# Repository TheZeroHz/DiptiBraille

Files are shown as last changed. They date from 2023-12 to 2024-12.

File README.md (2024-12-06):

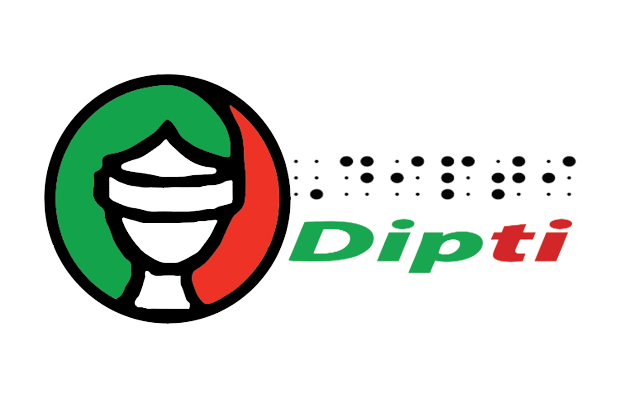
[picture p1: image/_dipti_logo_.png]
>  
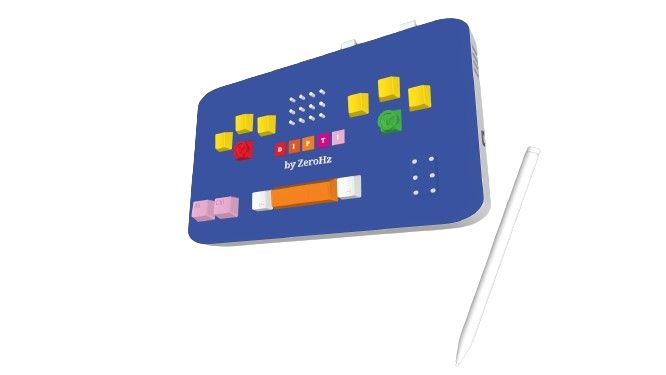
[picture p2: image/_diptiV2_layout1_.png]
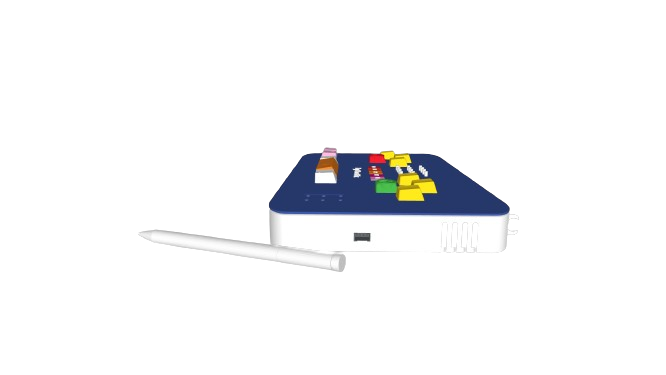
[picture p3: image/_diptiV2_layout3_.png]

<p>DiptiBraille is an affordable literacy device for the visually impaired, enabling text input using Braille. It supports document writing, reading, and audio playback for audiobooks. Users can connect an external Braille display for enhanced feedback. Wireless options include WiFi and WebShare for easy data transfer. Essential communication features like calls and SMS are included for seamless interaction.</p>

># Operating System
[DiptiOS 3](https://drive.google.com/drive/folders/1-XRWvRZWpASW5opDc2k0D57xcp3DkUi7?usp=sharing) is a pioneering operating system meticulously crafted to cater to the unique needs of braille users. Rooted in the robust framework of [FreeRTOS](https://www.freertos.org/RTOS.html), DiptiOS/3 sets a new standard for accessibility, seamlessly integrating with braille display hardware to deliver unparalleled functionality and ease of use.

Experience the sophistication of DiptiBraille's sleek design and intuitive interface, which offer both demo and pro versions. <b><i>Unlock the full potential with the Pro Version, priced at $50</i></b>, or explore its capabilities at no cost with the Demo Version.

|✅ available|❌ not available|🔄 upcoming|🟡 partially available|
|---|---|---|---|

| Features | Pro| Demo | Features | Pro|Demo |  Features | Pro|Demo |
|---|-----|---|---|-----|---|---|---|---|
| 📄 Doc Writing | ✅ |✅ |🖋️ Practice Writing | ✅|❌| 📚 Learn Writing| ✅ |🟡|
|📜 Doc Reading | ✅|✅ | 📖 Practice Reading|  ✅ |❌|📘 Learn Reading| ✅ |🟡|
|🎧 Audio Book |✅|✅ |🎵  Music Library  | 🔄 |❌ | 📞 Call|✅|🟡|
|💬 SMS |✅|❌| 🧮 Calculator | ✅|🟡 |⌨️ BLE KeyBoard| ✅ |✅|
|Bluetooth IconBluetooth|✅| ❌ | WebShare Icon WebShare| ✅ |❌| RemoteShell Icon RemoteShell|🔄| ❌ |
|WiFi Icon WiFi Manager| ✅|🟡 |⬇️ Download Manager |  ✅|❌ |📱 Phone Manager| ✅ |❌|
|⚡Continuous Updates |  ✅ |🟡| 🎮 Games | ✅ |🟡 |📻 Radio| ✅ |✅ |
### DiptiOS/3 Ensures
| OS Feature | Description |
|---|---|
| Optimized Braille Support | Comprehensive support for braille display devices ensures smooth input and output. |
| Intuitive Interface | User-friendly interface tailored for braille users prioritizes ease of navigation. |
| Real-Time Responsiveness | Built on FreeRTOS for instant feedback and interaction. |
| Customization Options | Personalize braille experience with customizable settings. |
| Seamless Connectivity | Effortless data exchange with other devices and platforms. |
| Enhanced Accessibility | Enjoy voice feedback and enhanced audio. |
| Reliability and Stability  | Backed by FreeRTOS for consistent performance and uptime. |

># Open Source Hardware
### Printed Circuit Boards
|**Base Material:** FR-4|**Layers:** 2|**Thickness:** 1.6 mm|**Surface:** HASL(with lead)|**Quality:** IPC 2|**Silkscreen:** White|
|---|---|---|---|---|---|

| Main Unit PCB Outlook | Additional Info | **Display Unit PCB Outlook**  | **Additional Info** |
|---|---|---|---|
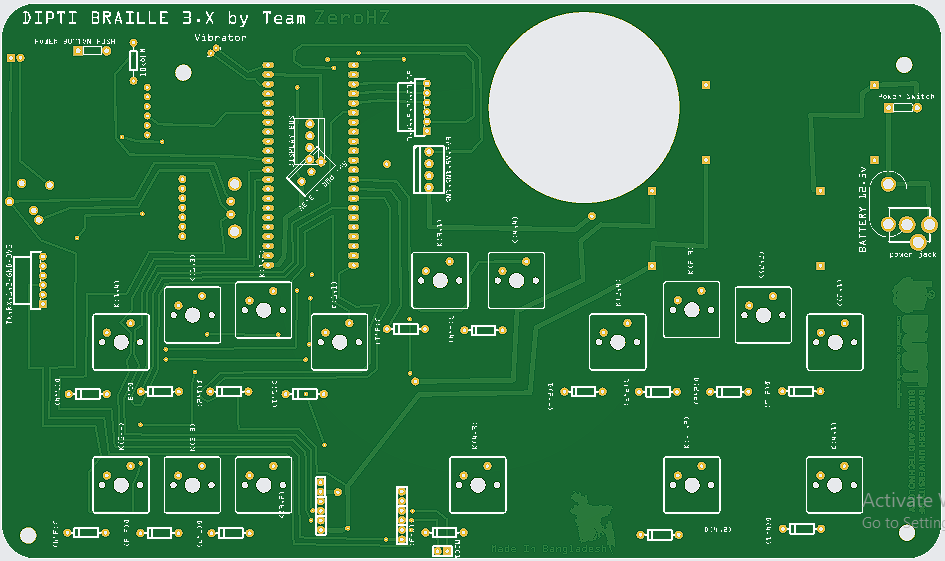
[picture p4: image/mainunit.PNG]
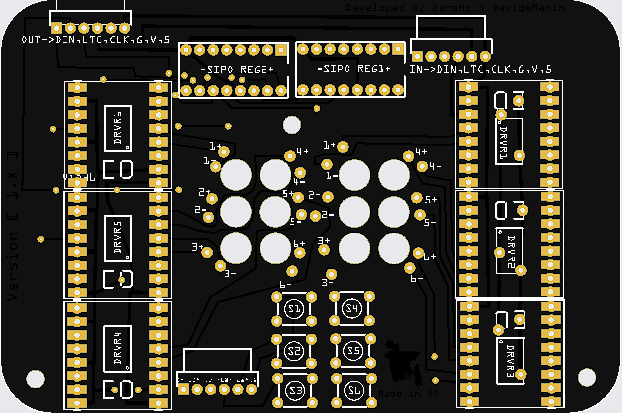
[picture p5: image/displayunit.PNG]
|  |<br> **Dim:** 251x148<br> **Color:** Green<br> |  |<br>**Dim:** 116x77<br> **Color:** Black |

### 🔧 Components List
| Component | Quantity | Component | Quantity |
|---|---|---|---|
| 💻 ESP32 S3 N16R8 | x1 | 📶 SIM800L GSM module | x1 |
| ⌨️ Cherry MX Mechanical keys | x16 | ⌨️ Mechanical Key Cap | x16 |
| 🔊 I2S Amplifier | x1 | 🔊 Speaker 3W | x1 |
| 📇 SD Card Module | x1 | 📇 SD Card | x1 |
| ⚙️ Motor Driver - TB6612FNG | x6 | 🔄 Shift Register - 74HC595 | x2 |
| 🔋 4.2v 2000mAh Li-on Battery | x3 | ⚡ BMS (Circuit Protector) | x1 |
| ⚡ 5V Constant Step Down BUCK Converter | x2 | 🔌 12v Laptop Charger | x1 |
| ⚡ Capacitor | x2 | ⚡ Diode | x20 |
| 🔘 Push Button | x10 | | |

# External Libraries We have Used
- [gpio_viewer](https://github.com/thelastoutpostworkshop/gpio_viewer) by [charlesgiguere](https://github.com/charlesgiguere)
- [ESP32-audioI2S](https://github.com/schreibfaul1/ESP32-audioI2S) by [schreibfaul1](https://github.com/schreibfaul1)
- [ESPFMfGK](https://github.com/holgerlembke/ESPFMfGK) by [Holger Lembke](https://github.com/holgerlembke)
- [WebSerialLite](https://github.com/asjdf/WebSerialLite) by [杨成锴](https://github.com/asjdf)
- [WifiManager](https://github.com/tzapu/WiFiManager) by [tzapu](https://github.com/tzapu)
- [Keypad](https://github.com/Chris--A/Keypad) by [Christopher Andrews](https://github.com/Chris--A)
- [ESPAsyncTCP](https://github.com/me-no-dev/ESPAsyncTCP) by [Me No Dev](https://github.com/me-no-dev)
- [ESPAsyncWebServer](https://github.com/me-no-dev/ESPAsyncWebServer) by [Me No Dev](https://github.com/me-no-dev)
- [ESP32-BLE-Keyboard](https://github.com/T-vK/ESP32-BLE-Keyboard) by [T-vK](https://github.com/T-vK)

  We express our gratitude❤️ to these developers for their remarkable libraries.

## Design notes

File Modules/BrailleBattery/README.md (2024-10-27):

# Battery Level Monitoring for 18650 Battery on ESP32

This code provides a simple method to monitor the charge level of a 18650 battery using the **Battery18650Stats** library and display the battery status as a visual bar chart in the serial monitor.

## Features

- **Battery Voltage Monitoring**: Reads the battery voltage and calculates the charge level.
- **Battery Charge Level Display**: Displays a graphical bar (0 to 5 bars) representing the charge level in the serial monitor.
- **Adjustable Polling Interval**: Updates the battery status every 2 seconds.

## Requirements

- **ESP32 Board** with Analog-to-Digital Converter (ADC) pin support.
- **Battery18650Stats Library**: This library is used for reading and interpreting battery charge levels based on voltage.
- **18650 Battery** connected to an ADC pin through a voltage divider if needed, depending on the ADC's range.

## Pin Configuration

- **ADC_PIN**: `GPIO 3` - Connected to the battery's output (through a voltage divider if necessary).

## Code Explanation

### Functions

- **`printBatteryBars(int chargeLevel)`**: Prints a graphical representation of the battery charge level in the form of a bar made of 5 segments.
  - Each segment represents 20% of the battery's charge.
  - A filled square (`■`) indicates 20% increments in charge, while an empty space represents remaining segments.

### Main Loop

1. **Reads Battery Charge and Voltage**:
   - `battery.getBatteryChargeLevel()` returns the battery's charge level as a percentage.
   - `battery.getBatteryVolts()` returns the current battery voltage.
   
2. **Displays Data**:
   - Prints the voltage and charge level in the serial monitor.
   - Calls `printBatteryBars()` to print a bar display of the charge status.

3. **Delay**: Pauses for 2 seconds before refreshing the values.

## Example Output

The output will look like this in the serial monitor:

```
Volts: 3.7
Charge level: 60
Battery Status: [■■■  ]
```

## Code

```cpp
#include <Arduino.h>
#include <Battery18650Stats.h>

#define ADC_PIN 3

Battery18650Stats battery(ADC_PIN);

void printBatteryBars(int chargeLevel) {
  Serial.print("Battery Status: [");
  for (int i = 0; i < 5; ++i) {
    if (chargeLevel >= (i + 1) * 20) {
      Serial.print("■");  // Unicode square character
    } else {
      Serial.print(" ");
    }
  }
  Serial.print("]");
  Serial.println();
}

void setup() {
  Serial.begin(115200);
}

void loop() {
  int chargeLevel = battery.getBatteryChargeLevel();
  float batteryVolts = battery.getBatteryVolts();

  Serial.print("Volts: ");
  Serial.println(batteryVolts);

  Serial.print("Charge level: ");
  Serial.println(chargeLevel);

  printBatteryBars(chargeLevel);

  delay(2000);
}
```

## Notes

- Make sure the `Battery18650Stats` library is installed and configured correctly.
- Ensure that the battery voltage does not exceed the maximum input voltage of the ADC pin used.
- Modify `ADC_PIN` if using a different analog pin.

This setup provides a straightforward way to monitor the battery level in your projects, making it ideal for battery-powered devices like remote sensors or portable gadgets.

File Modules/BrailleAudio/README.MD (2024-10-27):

# DiptiBraille Audio I2S ESP32 Integration

This code is part of the **DiptiBraille** project, an ESP32-based braille device designed to provide audio playback capabilities using I2S communication with integrated SD and WiFi functionalities. This setup allows the device to play audio files from both online streams and SD card storage, which can support various features for accessibility, including adjustable volume control and audio file management.

## Features

- **Audio Playback**: Supports audio streaming from both online sources and SD card files.
- **Queue-based Command System**: Uses FreeRTOS queues to handle audio commands, ensuring reliable command exchange.
- **Volume Control**: Allows dynamic setting and retrieval of volume levels.
- **File Management**: Integrates with an SD card to store and play local audio files.
- **WiFi Connectivity**: Connects to online audio streams via WiFi for continuous playback.

## Hardware Requirements

- **ESP32 Module**
- **MicroSD Card Module** (Connected to SPI)
- **I2S-compatible Amplifier or DAC Module** (for audio output)
  
### Pin Configuration

- **SD Card Pins**
  - `SD_CS`: GPIO 10
  - `SPI_MOSI`: GPIO 11
  - `SPI_MISO`: GPIO 13
  - `SPI_SCK`: GPIO 12
- **I2S Audio Pins**
  - `I2S_DOUT`: GPIO 6
  - `I2S_BCLK`: GPIO 5
  - `I2S_LRC`: GPIO 4

## Libraries Required

- [WiFi](https://github.com/espressif/arduino-esp32/tree/master/libraries/WiFi)
- [Audio](https://github.com/schreibfaul1/ESP32-audioI2S) (for audio processing)

## Usage

### 1. Initialization

Upon setup, the code:
1. Initializes the SD card and verifies connection.
2. Connects to WiFi using the specified credentials.
3. Starts the audio task, which handles audio commands using queues.

### 2. Audio Commands

The program uses a struct (`audioMessage`) to communicate commands between tasks, supporting the following commands:
- **SET_VOLUME**: Sets the audio volume (range 0-21).
- **GET_VOLUME**: Retrieves the current volume level.
- **CONNECTTOHOST**: Connects to an online audio stream.
- **CONNECTTOSD**: Plays an audio file from the SD card.

### 3. Serial Commands

You can control the playback and volume through the Serial interface:
- **Audio File Playback**: Send the filename of an audio file stored on the SD card.
- **Volume Control**: Send an integer (0–21) to adjust the volume.

### Code Overview

- **`audioTask()`**: Core function that processes commands from the queue, adjusts volume, and manages audio source connections.
- **`audioInit()`**: Initializes and pins the audio task to core 1, keeping it isolated for efficient handling.
- **`transmitReceive()`**: Sends commands and receives responses through queues, ensuring synchronized communication.
- **`setup()`**: Initializes all peripherals and starts an initial stream from an online host.

### Example Commands

- **Set Volume**: Send an integer (0–21) over Serial.
- **Play Audio from SD**: Send the filename (e.g., `audioFile.mp3`) over Serial.

## Dependencies

Ensure that all required libraries are installed and configured correctly in your environment.

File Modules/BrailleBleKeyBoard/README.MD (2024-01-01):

# ESP32 BLE Keyboard library

## Remark
To utilize this feature, PSRAM must be activated. On development boards equipped with the onboard 
ESP32-S3-WROOM-1 module series (utilizing 8-wire SPI flash/PSRAM), the GPIO pins GPIO35, GPIO36, and
GPIO37 are reserved for communication between the internal ESP32-S3 chip and the SPI flash/PSRAM.
These pins are not externally accessible when PSRAM is Activated.

## Features

 - [x] Send key strokes
 - [x] Send text
 - [x] Press/release individual keys
 - [x] Media keys are supported
 - [ ] Read Numlock/Capslock/Scrolllock state
 - [x] Set battery level (basically works, but doesn't show up in Android's status bar)
 - [x] Compatible with Android
 - [x] Compatible with Windows
 - [x] Compatible with Linux
 - [x] Compatible with MacOS X (not stable, some people have issues, doesn't work with old devices)
 - [x] Compatible with iOS (not stable, some people have issues, doesn't work with old devices)

## Example

``` C++
/**
 * This example turns the ESP32 into a Bluetooth LE keyboard that writes the words, presses Enter, presses a media key and then Ctrl+Alt+Delete
 */
#include <BleKeyboard.h>

BleKeyboard bleKeyboard;

void setup() {
  Serial.begin(115200);
  Serial.println("Starting BLE work!");
  bleKeyboard.begin();
}

void loop() {
  if(bleKeyboard.isConnected()) {
    Serial.println("Sending 'Hello world'...");
    bleKeyboard.print("Hello world");

    delay(1000);

    Serial.println("Sending Enter key...");
    bleKeyboard.write(KEY_RETURN);

    delay(1000);

    Serial.println("Sending Play/Pause media key...");
    bleKeyboard.write(KEY_MEDIA_PLAY_PAUSE);

    delay(1000);
    
   //
   // Below is an example of pressing multiple keyboard modifiers 
   // which by default is commented out. 
   // 
   /* Serial.println("Sending Ctrl+Alt+Delete...");
    bleKeyboard.press(KEY_LEFT_CTRL);
    bleKeyboard.press(KEY_LEFT_ALT);
    bleKeyboard.press(KEY_DELETE);
    delay(100);
    bleKeyboard.releaseAll();
    */

  }
  Serial.println("Waiting 5 seconds...");
  delay(5000);
}
```

## API docs
The BleKeyboard interface is almost identical to the Keyboard Interface, so you can use documentation right here:
https://www.arduino.cc/reference/en/language/functions/usb/keyboard/

Just remember that you have to use `bleKeyboard` instead of just `Keyboard` and you need these two lines at the top of your script:
```
#include <BleKeyboard.h>
BleKeyboard bleKeyboard;
```

In addition to that you can send media keys (which is not possible with the USB keyboard library). Supported are the following:
- KEY_MEDIA_NEXT_TRACK
- KEY_MEDIA_PREVIOUS_TRACK
- KEY_MEDIA_STOP
- KEY_MEDIA_PLAY_PAUSE
- KEY_MEDIA_MUTE
- KEY_MEDIA_VOLUME_UP
- KEY_MEDIA_VOLUME_DOWN
- KEY_MEDIA_WWW_HOME
- KEY_MEDIA_LOCAL_MACHINE_BROWSER // Opens "My Computer" on Windows
- KEY_MEDIA_CALCULATOR
- KEY_MEDIA_WWW_BOOKMARKS
- KEY_MEDIA_WWW_SEARCH
- KEY_MEDIA_WWW_STOP
- KEY_MEDIA_WWW_BACK
- KEY_MEDIA_CONSUMER_CONTROL_CONFIGURATION // Media Selection
- KEY_MEDIA_EMAIL_READER

There is also Bluetooth specific information that you can set (optional):
Instead of `BleKeyboard bleKeyboard;` you can do `BleKeyboard bleKeyboard("Bluetooth Device Name", "Bluetooth Device Manufacturer", 100);`. (Max lenght is 15 characters, anything beyond that will be truncated.)  
The third parameter is the initial battery level of your device. To adjust the battery level later on you can simply call e.g.  `bleKeyboard.setBatteryLevel(50)` (set battery level to 50%).  
By default the battery level will be set to 100%, the device name will be `ESP32 Bluetooth Keyboard` and the manufacturer will be `Espressif`.  
There is also a `setDelay` method to set a delay between each key event. E.g. `bleKeyboard.setDelay(10)` (10 milliseconds). The default is `8`.  
This feature is meant to compensate for some applications and devices that can't handle fast input and will skip letters if too many keys are sent in a small time frame.  

## NimBLE-Mode
The NimBLE mode enables a significant saving of RAM and FLASH memory.

### Comparison (SendKeyStrokes.ino at compile-time)

**Standard**
```
RAM:   [=         ]   9.3% (used 30548 bytes from 327680 bytes)
Flash: [========  ]  75.8% (used 994120 bytes from 1310720 bytes)
```

**NimBLE mode**
```
RAM:   [=         ]   8.3% (used 27180 bytes from 327680 bytes)
Flash: [====      ]  44.2% (used 579158 bytes from 1310720 bytes)
```

### Comparison (SendKeyStrokes.ino at run-time)

| | Standard | NimBLE mode | difference
|---|--:|--:|--:|
| `ESP.getHeapSize()` | 296.804 | 321.252 | **+ 24.448**  |
| `ESP.getFreeHeap()` | 143.572 | 260.764 | **+ 117.192** |
| `ESP.getSketchSize()` | 994.224 | 579.264 | **- 414.960** |

## How to activate NimBLE mode?

### ArduinoIDE: 
Uncomment the first line in BleKeyboard.h
```C++
#define USE_NIMBLE
```

### PlatformIO:
Change your `platformio.ini` to the following settings
```ini
lib_deps = 
  NimBLE-Arduino

build_flags = 
  -D USE_NIMBLE
```

## Credits

Credits to [chegewara](https://github.com/chegewara) and [the authors of the USB keyboard library](https://github.com/arduino-libraries/Keyboard/) as this project is heavily based on their work!  
Also, credits to [duke2421](https://github.com/T-vK/ESP32-BLE-Keyboard/issues/1) who helped a lot with testing, debugging and fixing the device descriptor!
And credits to [sivar2311](https://github.com/sivar2311) for adding NimBLE support, greatly reducing the memory footprint, fixing advertising issues and for adding the `setDelay` method.

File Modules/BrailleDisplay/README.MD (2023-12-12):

# Project Overview: Affordable Braille Display

## Introduction:
Initiated by DavideMarin, this project focuses on creating a cost-effective Braille display solution. The primary challenges addressed include reducing microcontroller pin usage, mitigating power and heating issues, and the introduction of a dedicated control library by ThezeroHz.

## Key Challenges and Solutions:

1. **Microcontroller Pin Reduction:**
   - **Challenge:** Controlling a Braille cell required a high number of microcontroller pins.
   - **Solution:** Integrated shift registers (SIPO) to control N display cells with just 3 microcontroller pins, significantly improving design feasibility.

2. **Power and Heating Issues:**
   - **Challenge:** Maintaining dot states for specific times led to heating issues.
   - **Solution:** Introduced a frequency-based approach, incorporating burn and cool coefficients, optimizing power usage and mitigating heating problems.

3. **User Interaction Challenges:**
   - **Challenge:** Unintended touch or movement altered dot states.
   - **Solution:** Implemented a mechanism to hold dot states for a dedicated time, enhancing stability and user interaction.

## Control Library by ThezeroHz:

- A dedicated display library has been developed by ThezeroHz, simplifying the process of managing and controlling Braille cells.

## Optimizing Dot State Maintenance:

- Introduced the concepts of burn coefficient, cool coefficient, and frequency to optimize dot state maintenance.

## Implementation Guidance:

- Developers can utilize the formula time = 1000/(Frequency*(burn+cool)) to configure the wave period based on project requirements.

**Conclusion:**

In summary, this project presents an innovative solution to control Braille displays affordably and efficiently. The integration of shift registers, power optimization, and user interaction improvements, coupled with ThezeroHz's control library, make this project a comprehensive solution for Braille display applications.

For more details and demonstrations, refer to [ZeroHz's YouTube Channel](https://www.youtube.com/channel/UCmclthI4TeyJ3pFr7iuGWrA). The dedicated control library by ThezeroHz adds an extra layer of convenience for developers working on similar projects.

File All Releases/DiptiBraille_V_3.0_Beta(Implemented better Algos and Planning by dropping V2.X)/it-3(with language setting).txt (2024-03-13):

#include "FS.h"
#include "SD.h"
#include "SPI.h"
#include <Keypad.h>
const byte ROWS = 4;
const byte COLS = 4;
char hexaKeys[ROWS][COLS] = {
  {'1', '4', 's', 'e'},
  {'2', '5', 'n', 'u'},
  {'3', '6', 'C', 'c'},
  {'*', 'b', '#', 'd'}
};
byte rowPins[ROWS] = {33, 22, 21, 4};
byte colPins[COLS] =  {25, 26, 27, 14}; // 18-sck, 5-cs, 23-mosi, 19-miso for sd
Keypad customKeypad = Keypad( makeKeymap(hexaKeys), rowPins, colPins, ROWS, COLS);
struct Point {
  String kerneldata, userdata;
};
#define root_menu_cnt 7
#define write_f_cnt 3
#define practice_writing_cnt 3
#define learn_writing_cnt 3
#define read_f_cnt 3
#define practice_reading_cnt 3
#define learn_reading_cnt 3
#define audio_book_cnt 3
#define calculator_cnt 4
#define wireless_cnt 2
#define settings_cnt 5
String set_data = "B000000";

enum pagetype {root_menu, write_f, read_f, audio_book, calculator, wireless, sim, settings, doc_writing, practice_writing, learn_writing, practice_alphabet_writing, practice_number_writing, practice_specialcharecter_writing, learn_alphabet_writing, learn_number_writing, learn_specialcharecter_writing,  doc_reading, practice_reading, learn_reading, practice_alphabet_reading, practice_number_reading, practice_specialcharecter_reading, learn_alphabet_reading, learn_number_reading, learn_specialcharecter_reading,  bengali_book, english_book, math_book,  addition, subtraction, multiplication, division, wifi, bluetooth, call, message, language, voice_output, braille_output, touch_pen, power};
enum pagetype c_page = root_menu;
void setup() {
  Serial.begin(115200);
  if (!SD.begin()) {
    Serial.println("Card Mount Failed");
    return;
  }
  uint8_t cardType = SD.cardType();

  if (cardType == CARD_NONE) {
    Serial.println("No SD card attached");
    return;
  }
  writeFile(SD, "/text.txt", "hello ");
}

void loop() {
  switch (c_page)
  {
    //root
    case root_menu: root_menu_page(); break;
    case write_f: write_f_page(); break;
    case read_f: read_f_page(); break;
    case audio_book: audio_book_page(); break;
    case calculator: calculator_page(); break;
    case wireless: wireless_page(); break;
    case sim: sim_page(); break;
    case settings: settings_page(); break;
    //write
    case doc_writing: doc_writing_page(); break;//write to text file
    case practice_writing: practice_writing_page(); break;
    case learn_writing: learn_writing_page(); break;
    //practice write
    case practice_alphabet_writing: practice_alphabet_writing_page(); break;
    case practice_number_writing: practice_number_writing_page(); break;
    case practice_specialcharecter_writing: practice_specialcharecter_writing_page(); break;
    //learn write
    case learn_alphabet_writing: learn_alphabet_writing_page(); break;
    case learn_number_writing: learn_number_writing_page(); break;
    case learn_specialcharecter_writing: learn_specialcharecter_writing_page(); break;
    //read
    case doc_reading: doc_reading_page(); break;//read to text file
    case practice_reading: practice_reading_page(); break;
    case learn_reading: learn_reading_page(); break;
    //practice read
    case practice_alphabet_reading: practice_alphabet_reading_page(); break;
    case practice_number_reading: practice_number_reading_page(); break;
    case practice_specialcharecter_reading: practice_specialcharecter_reading_page(); break;
    //learn read
    case learn_alphabet_reading: learn_alphabet_reading_page(); break;
    case learn_number_reading: learn_number_reading_page(); break;
    case learn_specialcharecter_reading: learn_specialcharecter_reading_page(); break;
    //audio book
    case bengali_book: bengali_book_page(); break;
    case english_book: english_book_page(); break;
    case math_book: math_book_page(); break;
    //calculator
    case addition: addition_page(); break;
    case subtraction: subtraction_page(); break;
    case multiplication: multiplication_page(); break;
    case division: division_page(); break;
    //wireless
    case wifi: wifi_page(); break;
    case bluetooth: bluetooth_page(); break;
    //sim
    case call: call_page(); break;
    case message: message_page(); break;
    //settings
    case language:  language_page(); break;
    case voice_output: voice_output_page(); break;
    case braille_output: braille_output_page(); break;
    case touch_pen: touch_pen_page(); break;
    case power: power_page(); break;
  }
}

//root menu
void root_menu_page(void)
{
  bool update_display = true;
  uint32_t loopstart;
  bool btn_accept_isdown = false;
  bool btn_up_isdown = false;
  bool btn_down_isdown = false;

  uint8_t sub_pos = 1;
  while (true)
  {
    loopstart = millis();
    if (update_display)
    {
      update_display = false;
      clear_screen();
      Serial.println(F("           welcome to root menu"));
      print_divider();
      print_selected(1, sub_pos); Serial.println(F("write"));
      print_selected(2, sub_pos); Serial.println(F("read"));
      print_selected(3, sub_pos); Serial.println(F("audio book"));
      print_selected(4, sub_pos); Serial.println(F("calculator"));
      print_selected(5, sub_pos); Serial.println(F("wireless"));
      print_selected(6, sub_pos); Serial.println(F("sim"));
      print_selected(7, sub_pos); Serial.println(F("settings"));
      Serial.println();
      Serial.println();
      print_divider();
    }
    char customKey = customKeypad.getKey();

    if (customKey == 'e') {
      btn_accept_isdown = true;
    }
    if (customKey == 'u') {
      btn_up_isdown = true;
    }
    if (customKey == 'd') {
      btn_down_isdown = true;
    }
    if (btn_down_isdown)
    {
      if (sub_pos == root_menu_cnt) {
        sub_pos = 1;
      } else {
        sub_pos++;
      }
      update_display = true;
      btn_down_isdown = false;
    }
    if (btn_up_isdown)
    {
      if (sub_pos == 1) {
        sub_pos = root_menu_cnt;
      } else {
        sub_pos--;
      }
      update_display = true;
      btn_up_isdown = false;
    }

    if (btn_accept_isdown)
    {
      switch (sub_pos)
      {
        case 1: c_page = write_f; return;
        case 2: c_page = read_f; return;
        case 3: c_page = audio_book; return;
        case 4: c_page = calculator; return;
        case 5: c_page = wireless; return;
        case 6: c_page = sim; return;
        case 7: c_page = settings; return;
      }
    }

    while (millis() - loopstart < 25) {
      delay(2);
    }
  }
}

//write section
void write_f_page(void)
{
  bool update_display = true;
  uint32_t loopstart;
  bool btn_cancel_isdown = false;
  bool btn_up_isdown = false;
  bool btn_down_isdown = false;
  bool btn_accept_isdown = false;

  uint8_t sub_pos = 1;
  while (true)
  {
    loopstart = millis();
    if (update_display)
    {
      update_display = false;
      clear_screen();
      Serial.println(F(" write "));
      print_divider();
      print_selected(1, sub_pos); Serial.println(F("doc writing"));
      print_selected(2, sub_pos); Serial.println(F("practice writing"));
      print_selected(3, sub_pos); Serial.println(F("learn writing"));
      Serial.println();
      Serial.println();
      print_divider();
    }

    char customKey = customKeypad.getKey();

    if (customKey == 'e') {
      btn_accept_isdown = true;
    }
    if (customKey == 'u') {
      btn_up_isdown = true;
    }
    if (customKey == 'd') {
      btn_down_isdown = true;
    }
    if (customKey == 'c') {
      btn_cancel_isdown = true;
    }

    if (btn_down_isdown)
    {
      if (sub_pos == write_f_cnt) {
        sub_pos = 1;
      } else {
        sub_pos++;
      }
      update_display = true;
      btn_down_isdown = false;
    }
    if (btn_up_isdown)
    {
      if (sub_pos == 1) {
        sub_pos = write_f_cnt;
      } else {
        sub_pos--;
      }
      update_display = true;
      btn_up_isdown = false;
    }

    if (btn_cancel_isdown) {
      c_page = root_menu; return;;
    }

    if (btn_accept_isdown)
    {
      switch (sub_pos)
      {
        case 1: c_page = doc_writing; return;
        case 2: c_page = practice_writing; return;
        case 3: c_page = learn_writing; return;
      }
    }

    while (millis() - loopstart < 25) {
      delay(2);
    }
  }
}

// doc writing section
void doc_writing_page(void)
{
  bool update_display = true;
  uint32_t loopstart;
  bool btn_cancel_isdown = false;
  bool btn_accept_isdown = false;
  while (true)
  {
    loopstart = millis();
    if (update_display)
    {
      update_display = false;
      clear_screen();
      Serial.println(F("        doc writing "));
      print_divider();
      print_selected(1, 1); Serial.println(F("write to text file"));
      Serial.println();
      print_divider();
    }
    char customKey = customKeypad.getKey();

    if (customKey == 'e') {
      btn_accept_isdown = true;
    }
    if (customKey == 'c') {
      btn_cancel_isdown = true;
    }
    if (btn_accept_isdown) {
      String st = braille_input();
      //Serial.println(st);
      String udata = kerneldata_to_userdata(st);
      Serial.println(udata);
      appendFile(SD, "/text.txt", udata);
      // readFile(SD, "/text.txt");
      btn_accept_isdown = false;
    }

    if (btn_cancel_isdown) {
      c_page = write_f; return;
    }
    while (millis() - loopstart < 25) {
      delay(2);
    }
  }
}
//practice writing section
void practice_writing_page(void)
{
  bool update_display = true;
  uint32_t loopstart;
  bool btn_cancel_isdown = false;
  bool btn_up_isdown = false;
  bool btn_down_isdown = false;
  bool btn_accept_isdown = false;

  uint8_t sub_pos = 1;
  while (true)
  {
    loopstart = millis();
    if (update_display)
    {
      update_display = false;
      clear_screen();
      Serial.println(F("        practice writing "));
      print_divider();
      print_selected(1, sub_pos); Serial.println(F("practice alphabet writing"));
      print_selected(2, sub_pos); Serial.println(F("practice number writing"));
      print_selected(3, sub_pos); Serial.println(F("practice special charecter writing"));
      Serial.println();
      Serial.println();
      print_divider();
    }

    char customKey = customKeypad.getKey();

    if (customKey == 'e') {
      btn_accept_isdown = true;
    }
    if (customKey == 'u') {
      btn_up_isdown = true;
    }
    if (customKey == 'd') {
      btn_down_isdown = true;
    }
    if (customKey == 'c') {
      btn_cancel_isdown = true;
    }
    if (btn_down_isdown)
    {
      if (sub_pos == practice_writing_cnt) {
        sub_pos = 1;
      } else {
        sub_pos++;
      }
      update_display = true;
      btn_down_isdown = false;
    }
    if (btn_up_isdown)
    {
      if (sub_pos == 1) {
        sub_pos = practice_writing_cnt;
      } else {
        sub_pos--;
      }
      update_display = true;
      btn_up_isdown = false;
    }

    if (btn_cancel_isdown) {
      c_page = write_f; return;
    }
    if (btn_accept_isdown)
    {
      switch (sub_pos)
      {
        case 1: c_page = practice_alphabet_writing; return;
        case 2: c_page = practice_number_writing; return;
        case 3: c_page =  practice_specialcharecter_writing; return;
      }
    }
    while (millis() - loopstart < 25) {
      delay(2);
    }
  }
}
//practice alphabet writing
void practice_alphabet_writing_page(void)
{
  bool update_display = true;
  uint32_t loopstart;
  bool btn_cancel_isdown = false;
  bool btn_accept_isdown = false;
  while (true)
  {
    loopstart = millis();
    if (update_display)
    {
      update_display = false;
      clear_screen();
      print_divider();
      print_selected(1, 1); Serial.println(F("practice alphabet writing"));
      Serial.println();
      print_divider();
    }
    char customKey = customKeypad.getKey();

    if (customKey == 'e') {
      btn_accept_isdown = true;
    }
    if (customKey == 'c') {
      btn_cancel_isdown = true;
    }
    if (btn_cancel_isdown) {
      c_page = practice_writing; return;
    }
    while (millis() - loopstart < 25) {
      delay(2);
    }
  }
}
//practice number writing
void practice_number_writing_page(void)
{
  bool update_display = true;
  uint32_t loopstart;
  bool btn_cancel_isdown = false;
  bool btn_accept_isdown = false;
  while (true)
  {
    loopstart = millis();
    if (update_display)
    {
      update_display = false;
      clear_screen();
      print_divider();
      print_selected(1, 1); Serial.println(F("practice number writing"));
      Serial.println();
      print_divider();
    }
    char customKey = customKeypad.getKey();

    if (customKey == 'a') {
      btn_accept_isdown = true;
    }
    if (customKey == 'c') {
      btn_cancel_isdown = true;
    }
    if (btn_cancel_isdown) {
      c_page = practice_writing; return;
    }
    while (millis() - loopstart < 25) {
      delay(2);
    }
  }
}
//practice special charecter writing
void practice_specialcharecter_writing_page(void)
{
  bool update_display = true;
  uint32_t loopstart;
  bool btn_cancel_isdown = false;
  bool btn_accept_isdown = false;
  while (true)
  {
    loopstart = millis();
    if (update_display)
    {
      update_display = false;
      clear_screen();
      print_divider();
      print_selected(1, 1); Serial.println(F("practice special charecter writing"));
      Serial.println();
      print_divider();
    }
    char customKey = customKeypad.getKey();

    if (customKey == 'e') {
      btn_accept_isdown = true;
    }
    if (customKey == 'c') {
      btn_cancel_isdown = true;
    }
    if (btn_cancel_isdown) {
      c_page = practice_writing; return;
    }
    while (millis() - loopstart < 25) {
      delay(2);
    }
  }
}
//learn writing section
void learn_writing_page(void)
{
  bool update_display = true;
  uint32_t loopstart;
  bool btn_cancel_isdown = false;
  bool btn_up_isdown = false;
  bool btn_down_isdown = false;
  bool btn_accept_isdown = false;

  uint8_t sub_pos = 1;
  while (true)
  {
    loopstart = millis();
    if (update_display)
    {
      update_display = false;
      clear_screen();
      Serial.println(F("        learn writing "));
      print_divider();
      print_selected(1, sub_pos); Serial.println(F("learn alphabet writing"));
      print_selected(2, sub_pos); Serial.println(F("learn number writing"));
      print_selected(3, sub_pos); Serial.println(F("learn special charecter writing"));
      Serial.println();
      Serial.println();
      print_divider();
    }

    char customKey = customKeypad.getKey();

    if (customKey == 'e') {
      btn_accept_isdown = true;
    }
    if (customKey == 'u') {
      btn_up_isdown = true;
    }
    if (customKey == 'd') {
      btn_down_isdown = true;
    }
    if (customKey == 'c') {
      btn_cancel_isdown = true;
    }

    if (btn_down_isdown)
    {
      if (sub_pos == learn_writing_cnt) {
        sub_pos = 1;
      } else {
        sub_pos++;
      }
      update_display = true;
      btn_down_isdown = false;
    }
    if (btn_up_isdown)
    {
      if (sub_pos == 1) {
        sub_pos = learn_writing_cnt;
      } else {
        sub_pos--;
      }
      update_display = true;
      btn_up_isdown = false;
    }

    if (btn_cancel_isdown) {
      c_page = write_f; return;
    }
    if (btn_accept_isdown)
    {
      switch (sub_pos)
      {
        case 1: c_page = learn_alphabet_writing; return;
        case 2: c_page = learn_number_writing; return;
        case 3: c_page =  learn_specialcharecter_writing; return;
      }
    }

    while (millis() - loopstart < 25) {
      delay(2);
    }
  }

}
//learn alphabet writing
void learn_alphabet_writing_page(void)
{
  bool update_display = true;
  uint32_t loopstart;
  bool btn_cancel_isdown = false;
  bool btn_accept_isdown = false;
  while (true)
  {
    loopstart = millis();
    if (update_display)
    {
      update_display = false;
      clear_screen();
      print_divider();
      print_selected(1, 1); Serial.println(F("learn alphabet writing"));
      Serial.println();
      print_divider();
    }
    char customKey = customKeypad.getKey();

    if (customKey == 'e') {
      btn_accept_isdown = true;
    }
    if (customKey == 'c') {
      btn_cancel_isdown = true;
    }
    if (btn_cancel_isdown) {
      c_page = learn_writing; return;
    }
    while (millis() - loopstart < 25) {
      delay(2);
    }
  }
}
//learn number writing
void learn_number_writing_page(void)
{
  bool update_display = true;
  uint32_t loopstart;
  bool btn_cancel_isdown = false;
  bool btn_accept_isdown = false;
  while (true)
  {
    loopstart = millis();
    if (update_display)
    {
      update_display = false;
      clear_screen();
      print_divider();
      print_selected(1, 1); Serial.println(F("learn number writing"));
      Serial.println();
      print_divider();
    }
    char customKey = customKeypad.getKey();

    if (customKey == 'e') {
      btn_accept_isdown = true;
    }
    if (customKey == 'c') {
      btn_cancel_isdown = true;
    }
    if (btn_cancel_isdown) {
      c_page = learn_writing; return;
    }
    while (millis() - loopstart < 25) {
      delay(2);
    }
  }
}
//learn special charecter writing
void learn_specialcharecter_writing_page(void)
{
  bool update_display = true;
  uint32_t loopstart;
  bool btn_cancel_isdown = false;
  bool btn_accept_isdown = false;
  while (true)
  {
    loopstart = millis();
    if (update_display)
    {
      update_display = false;
      clear_screen();
      print_divider();
      print_selected(1, 1); Serial.println(F("learn special charecter writing"));
      Serial.println();
      print_divider();
    }
    char customKey = customKeypad.getKey();

    if (customKey == 'e') {
      btn_accept_isdown = true;
    }
    if (customKey == 'c') {
      btn_cancel_isdown = true;
    }
    if (btn_cancel_isdown) {
      c_page = learn_writing; return;
    }
    while (millis() - loopstart < 25) {
      delay(2);
    }
  }
}
//read
void read_f_page(void)
{

  bool update_display = true;
  uint32_t loopstart;
  bool btn_cancel_isdown = false;
  bool btn_up_isdown = false;
  bool btn_down_isdown = false;
  bool btn_accept_isdown = false;

  uint8_t sub_pos = 1;
  while (true)
  {
    loopstart = millis();
    if (update_display)
    {
      update_display = false;
      clear_screen();
      Serial.println(F("reading "));
      print_divider();
      print_selected(1, sub_pos); Serial.println(F("doc reading"));
      print_selected(2, sub_pos); Serial.println(F("practice reading"));
      print_selected(3, sub_pos); Serial.println(F("learn reading"));
      Serial.println();
      Serial.println();
      print_divider();
    }

    char customKey = customKeypad.getKey();

    if (customKey == 'e') {
      btn_accept_isdown = true;
    }
    if (customKey == 'u') {
      btn_up_isdown = true;
    }
    if (customKey == 'd') {
      btn_down_isdown = true;
    }
    if (customKey == 'c') {
      btn_cancel_isdown = true;
    }
    if (btn_down_isdown)
    {
      if (sub_pos == read_f_cnt) {
        sub_pos = 1;
      } else {
        sub_pos++;
      }
      update_display = true;
      btn_down_isdown = false;
    }
    if (btn_up_isdown)
    {
      if (sub_pos == 1) {
        sub_pos = read_f_cnt;
      } else {
        sub_pos--;
      }
      update_display = true;
      btn_up_isdown = false;
    }

    if (btn_cancel_isdown) {
      c_page = root_menu; return;
    }
    if (btn_accept_isdown)
    {
      switch (sub_pos)
      {
        case 1: c_page = doc_reading; return;
        case 2: c_page = practice_reading; return;
        case 3: c_page = learn_reading; return;
      }
    }
    while (millis() - loopstart < 25) {
      delay(2);
    }
  }
}

// doc reading section
void doc_reading_page(void)
{
  bool update_display = true;
  uint32_t loopstart;
  bool btn_cancel_isdown = false;
  bool btn_accept_isdown = false;
  while (true)
  {
    loopstart = millis();
    if (update_display)
    {
      update_display = false;
      clear_screen();
      Serial.println(F("        doc reading "));
      print_divider();
      print_selected(1, 1); Serial.println(F("read to text file"));
      Serial.println();
      print_divider();
    }

    char customKey = customKeypad.getKey();

    if (customKey == 'e') {
      btn_accept_isdown = true;
    }
    if (customKey == 'c') {
      btn_cancel_isdown = true;
    }
    if (btn_cancel_isdown) {
      c_page = read_f; return;
    }
    if (btn_accept_isdown)
    {
      readFile(SD, "/text.txt");
      btn_accept_isdown = false;
    }
    while (millis() - loopstart < 25) {
      delay(2);
    }
  }
}
//practice reading section
void practice_reading_page(void)
{
  bool update_display = true;
  uint32_t loopstart;
  bool btn_cancel_isdown = false;
  bool btn_up_isdown = false;
  bool btn_down_isdown = false;
  bool btn_accept_isdown = false;

  uint8_t sub_pos = 1;
  while (true)
  {
    loopstart = millis();
    if (update_display)
    {
      update_display = false;
      clear_screen();
      Serial.println(F("        practice reading "));
      print_divider();
      print_selected(1, sub_pos); Serial.println(F("practice alphabet reading"));
      print_selected(2, sub_pos); Serial.println(F("practice number reading"));
      print_selected(3, sub_pos); Serial.println(F("practice special charecter reading"));
      Serial.println();
      Serial.println();
      print_divider();
    }

    char customKey = customKeypad.getKey();

    if (customKey == 'e') {
      btn_accept_isdown = true;
    }
    if (customKey == 'u') {
      btn_up_isdown = true;
    }
    if (customKey == 'd') {
      btn_down_isdown = true;
    }
    if (customKey == 'c') {
      btn_cancel_isdown = true;
    }
    if (btn_down_isdown)
    {
      if (sub_pos == practice_reading_cnt) {
        sub_pos = 1;
      } else {
        sub_pos++;
      }
      update_display = true;
      btn_down_isdown = false;
    }
    if (btn_up_isdown)
    {
      if (sub_pos == 1) {
        sub_pos = practice_reading_cnt;
      } else {
        sub_pos--;
      }
      update_display = true;
      btn_up_isdown = false;
    }

    if (btn_cancel_isdown) {
      c_page = read_f; return;
    }
    if (btn_accept_isdown)
    {
      switch (sub_pos)
      {
        case 1: c_page = practice_alphabet_reading; return;
        case 2: c_page = practice_number_reading; return;
        case 3: c_page =  practice_specialcharecter_reading; return;
      }
    }
    while (millis() - loopstart < 25) {
      delay(2);
    }
  }
}
//practice alphabet reading
void practice_alphabet_reading_page(void)
{
  bool update_display = true;
  uint32_t loopstart;
  bool btn_cancel_isdown = false;
  bool btn_accept_isdown = false;
  while (true)
  {
    loopstart = millis();
    if (update_display)
    {
      update_display = false;
      clear_screen();
      print_divider();
      print_selected(1, 1); Serial.println(F("practice alphabet reading"));
      Serial.println();
      print_divider();
    }
    char customKey = customKeypad.getKey();

    if (customKey == 'e') {
      btn_accept_isdown = true;
    }
    if (customKey == 'c') {
      btn_cancel_isdown = true;
    }
    if (btn_cancel_isdown) {
      c_page = practice_reading; return;
    }
    while (millis() - loopstart < 25) {
      delay(2);
    }
  }
}
//practice number reading
void practice_number_reading_page(void)
{
  bool update_display = true;
  uint32_t loopstart;
  bool btn_cancel_isdown = false;
  bool btn_accept_isdown = false;
  while (true)
  {
    loopstart = millis();
    if (update_display)
    {
      update_display = false;
      clear_screen();
      print_divider();
      print_selected(1, 1); Serial.println(F("practice number reading"));
      Serial.println();
      print_divider();
    }
    char customKey = customKeypad.getKey();

    if (customKey == 'e') {
      btn_accept_isdown = true;
    }
    if (customKey == 'c') {
      btn_cancel_isdown = true;
    }
    if (btn_cancel_isdown) {
      c_page = practice_reading; return;
    }
    while (millis() - loopstart < 25) {
      delay(2);
    }
  }
}
//practice special charecter reading
void practice_specialcharecter_reading_page(void)
{
  bool update_display = true;
  uint32_t loopstart;
  bool btn_cancel_isdown = false;
  bool btn_accept_isdown = false;
  while (true)
  {
    loopstart = millis();
    if (update_display)
    {
      update_display = false;
      clear_screen();
      print_divider();
      print_selected(1, 1); Serial.println(F("practice special charecter reading"));
      Serial.println();
      print_divider();
    }
    char customKey = customKeypad.getKey();

    if (customKey == 'e') {
      btn_accept_isdown = true;
    }
    if (customKey == 'c') {
      btn_cancel_isdown = true;
    }
    if (btn_cancel_isdown) {
      c_page = practice_reading; return;
    }
    while (millis() - loopstart < 25) {
      delay(2);
    }
  }
}
//learn reading section
void learn_reading_page(void)
{
  bool update_display = true;
  uint32_t loopstart;
  bool btn_cancel_isdown = false;
  bool btn_up_isdown = false;
  bool btn_down_isdown = false;
  bool btn_accept_isdown = false;

  uint8_t sub_pos = 1;
  while (true)
  {
    loopstart = millis();
    if (update_display)
    {
      update_display = false;
      clear_screen();
      Serial.println(F("        learn reading "));
      print_divider();
      print_selected(1, sub_pos); Serial.println(F("learn alphabet reading"));
      print_selected(2, sub_pos); Serial.println(F("learn number reading"));
      print_selected(3, sub_pos); Serial.println(F("learn special charecter reading"));
      Serial.println();
      Serial.println();
      print_divider();
    }
    char customKey = customKeypad.getKey();

    if (customKey == 'e') {
      btn_accept_isdown = true;
    }
    if (customKey == 'u') {
      btn_up_isdown = true;
    }
    if (customKey == 'd') {
      btn_down_isdown = true;
    }
    if (customKey == 'c') {
      btn_cancel_isdown = true;
    }
    if (btn_down_isdown)
    {
      if (sub_pos == learn_reading_cnt) {
        sub_pos = 1;
      } else {
        sub_pos++;
      }
      update_display = true;
      btn_down_isdown = false;
    }
    if (btn_up_isdown)
    {
      if (sub_pos == 1) {
        sub_pos = learn_reading_cnt;
      } else {
        sub_pos--;
      }
      update_display = true;
      btn_up_isdown = false;
    }

    if (btn_cancel_isdown) {
      c_page = read_f; return;
    }
    if (btn_accept_isdown)
    {
      switch (sub_pos)
      {
        case 1: c_page = learn_alphabet_reading; return;
        case 2: c_page = learn_number_reading; return;
        case 3: c_page =  learn_specialcharecter_reading; return;
      }
    }

    while (millis() - loopstart < 25) {
      delay(2);
    }
  }

}
//learn alphabet reading
void learn_alphabet_reading_page(void)
{
  bool update_display = true;
  uint32_t loopstart;
  bool btn_cancel_isdown = false;
  bool btn_accept_isdown = false;
  while (true)
  {
    loopstart = millis();
    if (update_display)
    {
      update_display = false;
      clear_screen();
      print_divider();
      print_selected(1, 1); Serial.println(F("learn alphabet reading"));
      Serial.println();
      print_divider();
    }
    char customKey = customKeypad.getKey();

    if (customKey == 'e') {
      btn_accept_isdown = true;
    }
    if (customKey == 'c') {
      btn_cancel_isdown = true;
    }
    if (btn_cancel_isdown) {
      c_page = learn_reading; return;
    }
    while (millis() - loopstart < 25) {
      delay(2);
    }
  }
}
//learn number reading
void learn_number_reading_page(void)
{
  bool update_display = true;
  uint32_t loopstart;
  bool btn_cancel_isdown = false;
  bool btn_accept_isdown = false;
  while (true)
  {
    loopstart = millis();
    if (update_display)
    {
      update_display = false;
      clear_screen();
      print_divider();
      print_selected(1, 1); Serial.println(F("learn number reading"));
      Serial.println();
      print_divider();
    }
    char customKey = customKeypad.getKey();

    if (customKey == 'e') {
      btn_accept_isdown = true;
    }
    if (customKey == 'c') {
      btn_cancel_isdown = true;
    }
    if (btn_cancel_isdown) {
      c_page = learn_reading; return;
    }
    while (millis() - loopstart < 25) {
      delay(2);
    }
  }
}
//learn special charecter reading
void learn_specialcharecter_reading_page(void)
{
  bool update_display = true;
  uint32_t loopstart;
  bool btn_cancel_isdown = false;
  bool btn_accept_isdown = false;
  while (true)
  {
    loopstart = millis();
    if (update_display)
    {
      update_display = false;
      clear_screen();
      print_divider();
      print_selected(1, 1); Serial.println(F("learn special charecter reading"));
      Serial.println();
      print_divider();
    }
    char customKey = customKeypad.getKey();

    if (customKey == 'e') {
      btn_accept_isdown = true;
    }
    if (customKey == 'c') {
      btn_cancel_isdown = true;
    }
    if (btn_cancel_isdown) {
      c_page = learn_reading; return;
    }
    while (millis() - loopstart < 25) {
      delay(2);
    }
  }
}
//audio_book
void audio_book_page(void)
{
  bool update_display = true;
  uint32_t loopstart;
  bool btn_cancel_isdown = false;
  bool btn_up_isdown = false;
  bool btn_down_isdown = false;
  bool btn_accept_isdown = false;

  uint8_t sub_pos = 1;
  while (true)
  {
    loopstart = millis();
    if (update_display)
    {
      update_display = false;
      clear_screen();
      Serial.println(F("listen audio book "));
      print_divider();
      print_selected(1, sub_pos); Serial.println(F("bengali book"));
      print_selected(2, sub_pos); Serial.println(F("english book"));
      print_selected(3, sub_pos); Serial.println(F("math book"));
      Serial.println();
      Serial.println();
      print_divider();
    }

    char customKey = customKeypad.getKey();

    if (customKey == 'e') {
      btn_accept_isdown = true;
    }
    if (customKey == 'u') {
      btn_up_isdown = true;
    }
    if (customKey == 'd') {
      btn_down_isdown = true;
    }
    if (customKey == 'c') {
      btn_cancel_isdown = true;
    }

    if (btn_down_isdown)
    {
      if (sub_pos == audio_book_cnt) {
        sub_pos = 1;
      } else {
        sub_pos++;
      }
      update_display = true;
      btn_down_isdown = false;
    }
    if (btn_up_isdown)
    {
      if (sub_pos == 1) {
        sub_pos = audio_book_cnt;
      } else {
        sub_pos--;
      }
      update_display = true;
      btn_up_isdown = false;
    }

    if (btn_cancel_isdown) {
      c_page = root_menu; return;;
    }

    if (btn_accept_isdown)
    {
      switch (sub_pos)
      {
        case 1: c_page = bengali_book; return;
        case 2: c_page = english_book; return;
        case 3: c_page = math_book; return;
      }
    }

    while (millis() - loopstart < 25) {
      delay(2);
    }
  }
}
void bengali_book_page()
{
  bool update_display = true;
  uint32_t loopstart;
  bool btn_cancel_isdown = false;
  bool btn_accept_isdown = false;
  while (true)
  {
    loopstart = millis();
    if (update_display)
    {
      update_display = false;
      clear_screen();
      Serial.println(F("        bengali book"));
      print_divider();
      print_selected(1, 1); Serial.println(F("play bengali.wav"));
      Serial.println();
      print_divider();
    }
    char customKey = customKeypad.getKey();

    if (customKey == 'e') {
      btn_accept_isdown = true;
    }
    if (customKey == 'c') {
      btn_cancel_isdown = true;
    }
    if (btn_cancel_isdown) {
      c_page = audio_book; return;
    }
    while (millis() - loopstart < 25) {
      delay(2);
    }
  }
}
void english_book_page()
{
  bool update_display = true;
  uint32_t loopstart;
  bool btn_cancel_isdown = false;
  bool btn_accept_isdown = false;
  while (true)
  {
    loopstart = millis();
    if (update_display)
    {
      update_display = false;
      clear_screen();
      Serial.println(F("        english book"));
      print_divider();
      print_selected(1, 1); Serial.println(F("play english.wav"));
      Serial.println();
      print_divider();
    }
    char customKey = customKeypad.getKey();

    if (customKey == 'e') {
      btn_accept_isdown = true;
    }
    if (customKey == 'c') {
      btn_cancel_isdown = true;
    }
    if (btn_cancel_isdown) {
      c_page = audio_book; return;
    }
    while (millis() - loopstart < 25) {
      delay(2);
    }
  }
}
void math_book_page()
{
  bool update_display = true;
  uint32_t loopstart;
  bool btn_cancel_isdown = false;
  bool btn_accept_isdown = false;
  while (true)
  {
    loopstart = millis();
    if (update_display)
    {
      update_display = false;
      clear_screen();
      Serial.println(F("        math book"));
      print_divider();
      print_selected(1, 1); Serial.println(F("play math.wav"));
      Serial.println();
      print_divider();
    }
    char customKey = customKeypad.getKey();

    if (customKey == 'e') {
      btn_accept_isdown = true;
    }
    if (customKey == 'c') {
      btn_cancel_isdown = true;
    }
    if (btn_cancel_isdown) {
      c_page = audio_book; return;
    }
    while (millis() - loopstart < 25) {
      delay(2);
    }
  }
}

void calculator_page(void)
{
  bool update_display = true;
  uint32_t loopstart;
  bool btn_cancel_isdown = false;
  bool btn_up_isdown = false;
  bool btn_down_isdown = false;
  bool btn_accept_isdown = false;

  uint8_t sub_pos = 1;
  while (true)
  {
    loopstart = millis();
    if (update_display)
    {
      update_display = false;
      clear_screen();
      Serial.println(F("welcome to calculator "));
      print_divider();
      print_selected(1, sub_pos); Serial.println(F("addition"));
      print_selected(2, sub_pos); Serial.println(F("subtraction"));
      print_selected(3, sub_pos); Serial.println(F("multiplication"));
      print_selected(4, sub_pos); Serial.println(F("divison"));
      Serial.println();
      Serial.println();
      print_divider();
    }

    char customKey = customKeypad.getKey();

    if (customKey == 'e') {
      btn_accept_isdown = true;
    }
    if (customKey == 'u') {
      btn_up_isdown = true;
    }
    if (customKey == 'd') {
      btn_down_isdown = true;
    }
    if (customKey == 'c') {
      btn_cancel_isdown = true;
    }

    if (btn_down_isdown)
    {
      if (sub_pos == calculator_cnt) {
        sub_pos = 1;
      } else {
        sub_pos++;
      }
      update_display = true;
      btn_down_isdown = false;
    }
    if (btn_up_isdown)
    {
      if (sub_pos == 1) {
        sub_pos = calculator_cnt;
      } else {
        sub_pos--;
      }
      update_display = true;
      btn_up_isdown = false;
    }

    if (btn_cancel_isdown) {
      c_page = root_menu; return;;
    }

    if (btn_accept_isdown)
    {
      switch (sub_pos)
      {
        case 1: c_page = addition; return;
        case 2: c_page = subtraction; return;
        case 3: c_page = multiplication; return;
        case 4: c_page = division; return;
      }
    }

    while (millis() - loopstart < 25) {
      delay(2);
    }
  }
}
void addition_page()
{
  bool update_display = true;
  uint32_t loopstart;
  bool btn_cancel_isdown = false;
  bool btn_accept_isdown = false;
  while (true)
  {
    loopstart = millis();
    if (update_display)
    {
      update_display = false;
      clear_screen();
      Serial.println(F("        addition"));
      print_divider();
      print_selected(1, 1); Serial.println(F("A+B"));
      Serial.println();
      print_divider();
    }
    char customKey = customKeypad.getKey();

    if (customKey == 'e') {
      btn_accept_isdown = true;
    }
    if (customKey == 'c') {
      btn_cancel_isdown = true;
    }
    if (btn_cancel_isdown) {
      c_page = calculator; return;
    }
    while (millis() - loopstart < 25) {
      delay(2);
    }
  }
}
void subtraction_page()
{
  bool update_display = true;
  uint32_t loopstart;
  bool btn_cancel_isdown = false;
  bool btn_accept_isdown = false;
  while (true)
  {
    loopstart = millis();
    if (update_display)
    {
      update_display = false;
      clear_screen();
      Serial.println(F("        subtraction"));
      print_divider();
      print_selected(1, 1); Serial.println(F("A-B"));
      Serial.println();
      print_divider();
    }
    char customKey = customKeypad.getKey();

    if (customKey == 'e') {
      btn_accept_isdown = true;
    }
    if (customKey == 'c') {
      btn_cancel_isdown = true;
    }
    if (btn_cancel_isdown) {
      c_page = calculator; return;
    }
    while (millis() - loopstart < 25) {
      delay(2);
    }
  }
}
void multiplication_page()
{
  bool update_display = true;
  uint32_t loopstart;
  bool btn_cancel_isdown = false;
  bool btn_accept_isdown = false;
  while (true)
  {
    loopstart = millis();
    if (update_display)
    {
      update_display = false;
      clear_screen();
      Serial.println(F("        multiplication"));
      print_divider();
      print_selected(1, 1); Serial.println(F("A*B"));
      Serial.println();
      print_divider();
    }
    char customKey = customKeypad.getKey();

    if (customKey == 'e') {
      btn_accept_isdown = true;
    }
    if (customKey == 'c') {
      btn_cancel_isdown = true;
    }
    if (btn_cancel_isdown) {
      c_page = calculator; return;
    }
    while (millis() - loopstart < 25) {
      delay(2);
    }
  }
}
void division_page()
{
  bool update_display = true;
  uint32_t loopstart;
  bool btn_cancel_isdown = false;
  bool btn_accept_isdown = false;
  while (true)
  {
    loopstart = millis();
    if (update_display)
    {
      update_display = false;
      clear_screen();
      Serial.println(F("        division"));
      print_divider();
      print_selected(1, 1); Serial.println(F("A/B"));
      Serial.println();
      print_divider();
    }
    char customKey = customKeypad.getKey();

    if (customKey == 'e') {
      btn_accept_isdown = true;
    }
    if (customKey == 'c') {
      btn_cancel_isdown = true;
    }
    if (btn_cancel_isdown) {
      c_page = calculator; return;
    }
    while (millis() - loopstart < 25) {
      delay(2);
    }
  }
}

void wireless_page(void)
{
  bool update_display = true;
  uint32_t loopstart;
  bool btn_cancel_isdown = false;
  bool btn_up_isdown = false;
  bool btn_down_isdown = false;
  bool btn_accept_isdown = false;

  uint8_t sub_pos = 1;
  while (true)
  {
    loopstart = millis();
    if (update_display)
    {
      update_display = false;
      clear_screen();
      Serial.println(F("welcome to wireless section "));
      print_divider();
      print_selected(1, sub_pos); Serial.println(F("wifi"));
      print_selected(2, sub_pos); Serial.println(F("bluetooth"));
      Serial.println();
      Serial.println();
      print_divider();
    }

    char customKey = customKeypad.getKey();

    if (customKey == 'e') {
      btn_accept_isdown = true;
    }
    if (customKey == 'c') {
      btn_cancel_isdown = true;
    }
    if (customKey == 'u') {
      btn_up_isdown = true;
    }
    if (customKey == 'd') {
      btn_down_isdown = true;
    }

    if (btn_down_isdown)
    {
      if (sub_pos == wireless_cnt) {
        sub_pos = 1;
      } else {
        sub_pos++;
      }
      update_display = true;
      btn_down_isdown = false;
    }
    if (btn_up_isdown)
    {
      if (sub_pos == 1) {
        sub_pos = wireless_cnt;
      } else {
        sub_pos--;
      }
      update_display = true;
      btn_up_isdown = false;
    }

    if (btn_cancel_isdown) {
      c_page = root_menu; return;;
    }
    if (btn_accept_isdown)
    {
      switch (sub_pos)
      {
        case 1: c_page = wifi; return;
        case 2: c_page = bluetooth; return;
      }
    }
    while (millis() - loopstart < 25) {
      delay(2);
    }
  }
}
void wifi_page()
{
  bool update_display = true;
  uint32_t loopstart;
  bool btn_cancel_isdown = false;
  bool btn_up_isdown = false;
  bool btn_down_isdown = false;
  bool btn_accept_isdown = false;

  uint8_t sub_pos = 1;
  while (true)
  {
    loopstart = millis();
    if (update_display)
    {
      update_display = false;
      clear_screen();
      Serial.println(F("welcome to wifi section "));
      print_divider();
      print_selected(1, sub_pos); Serial.println(F("enter wifi ssid"));
      print_selected(2, sub_pos); Serial.println(F("enter wifi password"));
      print_selected(3, sub_pos); Serial.println(F("press enter to set credential"));
      Serial.println();
      Serial.println();
      print_divider();
    }

    char customKey = customKeypad.getKey();

    if (customKey == 'e') {
      btn_accept_isdown = true;
    }
    if (customKey == 'u') {
      btn_up_isdown = true;
    }
    if (customKey == 'd') {
      btn_down_isdown = true;
    }
    if (customKey == 'c') {
      btn_cancel_isdown = true;
    }

    if (btn_down_isdown)
    {
      if (sub_pos == 3) {
        sub_pos = 1;
      } else {
        sub_pos++;
      }
      update_display = true;
      btn_down_isdown = false;
    }
    if (btn_up_isdown)
    {
      if (sub_pos == 1) {
        sub_pos = 3;
      } else {
        sub_pos--;
      }
      update_display = true;
      btn_up_isdown = false;
    }

    if (btn_cancel_isdown) {
      c_page = wireless; return;;
    }
    if (btn_accept_isdown)
    {
      switch (sub_pos)
      {
        case 1:
          Serial.println(F("                                  enter ssid"));
          while (Serial.available() == 0) {
            String ssid = Serial.readString();

            if (ssid != NULL) {
              Serial.println(ssid);
              return;
            }

            if (btn_cancel_isdown)break;
          }

        case 2:
          Serial.println(F("                                  enter password"));
        case 3:
          Serial.println(F("                                  *set credential"));
      }
    }
    while (millis() - loopstart < 25) {
      delay(2);
    }
  }
}
void bluetooth_page()
{
  bool update_display = true;
  uint32_t loopstart;
  bool btn_cancel_isdown = false;
  bool btn_up_isdown = false;
  bool btn_down_isdown = false;
  bool btn_accept_isdown = false;

  uint8_t sub_pos = 1;
  while (true)
  {
    loopstart = millis();
    if (update_display)
    {
      update_display = false;
      clear_screen();
      Serial.println(F("welcome to bluetooth section "));
      print_divider();
      print_selected(1, sub_pos); Serial.println(F("turn on bluetooth"));
      print_selected(2, sub_pos); Serial.println(F("turn off bluetooth"));
      Serial.println();
      Serial.println();
      print_divider();
    }
    char customKey = customKeypad.getKey();

    if (customKey == 'e') {
      btn_accept_isdown = true;
    }
    if (customKey == 'u') {
      btn_up_isdown = true;
    }
    if (customKey == 'd') {
      btn_down_isdown = true;
    }
    if (customKey == 'c') {
      btn_cancel_isdown = true;
    }

    if (btn_down_isdown)
    {
      if (sub_pos == 2) {
        sub_pos = 1;
      } else {
        sub_pos++;
      }
      update_display = true;
      btn_down_isdown = false;
    }
    if (btn_up_isdown)
    {
      if (sub_pos == 1) {
        sub_pos = 2;
      } else {
        sub_pos--;
      }
      update_display = true;
      btn_up_isdown = false;
    }

    if (btn_cancel_isdown) {
      c_page = wireless; return;;
    }
    if (btn_accept_isdown)
    {
      switch (sub_pos)
      {
        case 1: Serial.println(F("                                  *turned on bluetooth"));
        case 2: Serial.println(F("                                  *turned off bluetooth"));
      }
    }
    while (millis() - loopstart < 25) {
      delay(2);
    }
  }
}
//sim section
void sim_page(void)
{
  bool update_display = true;
  uint32_t loopstart;
  bool btn_cancel_isdown = false;
  bool btn_up_isdown = false;
  bool btn_down_isdown = false;
  bool btn_accept_isdown = false;

  uint8_t sub_pos = 1;
  while (true)
  {
    loopstart = millis();
    if (update_display)
    {
      update_display = false;
      clear_screen();
      Serial.println(F("welcome to sim section "));
      print_divider();
      print_selected(1, sub_pos); Serial.println(F("call"));
      print_selected(2, sub_pos); Serial.println(F("message"));
      Serial.println();
      Serial.println();
      print_divider();
    }

    char customKey = customKeypad.getKey();

    if (customKey == 'e') {
      btn_accept_isdown = true;
    }
    if (customKey == 'u') {
      btn_up_isdown = true;
    }
    if (customKey == 'd') {
      btn_down_isdown = true;
    }
    if (customKey == 'c') {
      btn_cancel_isdown = true;
    }

    if (btn_down_isdown)
    {
      if (sub_pos == 2) {
        sub_pos = 1;
      } else {
        sub_pos++;
      }
      update_display = true;
      btn_down_isdown = false;
    }
    if (btn_up_isdown)
    {
      if (sub_pos == 1) {
        sub_pos = 2;
      } else {
        sub_pos--;
      }
      update_display = true;
      btn_up_isdown = false;
    }

    if (btn_cancel_isdown) {
      c_page = root_menu; return;;
    }
    if (btn_accept_isdown)
    {
      switch (sub_pos)
      {
        case 1: c_page = call; return;
        case 2: c_page = message; return;
      }
    }
    while (millis() - loopstart < 25) {
      delay(2);
    }
  }
}
void call_page()
{
  bool update_display = true;
  uint32_t loopstart;
  bool btn_cancel_isdown = false;
  bool btn_accept_isdown = false;
  while (true)
  {
    loopstart = millis();
    if (update_display)
    {
      update_display = false;
      clear_screen();
      Serial.println(F("        call"));
      print_divider();
      print_selected(1, 1); Serial.println(F("call to x"));
      Serial.println();
      print_divider();
    }
    char customKey = customKeypad.getKey();

    if (customKey == 'e') {
      btn_accept_isdown = true;
    }
    if (customKey == 'c') {
      btn_cancel_isdown = true;
    }
    if (btn_cancel_isdown) {
      c_page = sim; return;
    }
    while (millis() - loopstart < 25) {
      delay(2);
    }
  }
}
void message_page()
{
  bool update_display = true;
  uint32_t loopstart;
  bool btn_cancel_isdown = false;
  bool btn_accept_isdown = false;
  while (true)
  {
    loopstart = millis();
    if (update_display)
    {
      update_display = false;
      clear_screen();
      Serial.println(F("        message"));
      print_divider();
      print_selected(1, 1); Serial.println(F("message to x"));
      Serial.println();
      print_divider();
    }
    char customKey = customKeypad.getKey();

    if (customKey == 'e') {
      btn_accept_isdown = true;
    }
    if (customKey == 'c') {
      btn_cancel_isdown = true;
    }
    if (btn_cancel_isdown) {
      c_page = sim; return;
    }
    while (millis() - loopstart < 25) {
      delay(2);
    }
  }
}
//settings
void settings_page(void)
{
  bool update_display = true;
  uint32_t loopstart;
  bool btn_cancel_isdown = false;
  bool btn_up_isdown = false;
  bool btn_down_isdown = false;
  bool btn_accept_isdown = false;

  uint8_t sub_pos = 1;
  while (true)
  {
    loopstart = millis();
    if (update_display)
    {
      update_display = false;
      clear_screen();
      Serial.println(F("welcome to settings "));
      print_divider();
      print_selected(1, sub_pos); Serial.println(F("language"));
      print_selected(2, sub_pos); Serial.println(F("voice output"));
      print_selected(3, sub_pos); Serial.println(F("braille output"));
      print_selected(4, sub_pos); Serial.println(F("touch pen"));
      print_selected(5, sub_pos); Serial.println(F("power"));
      Serial.println();
      Serial.println();
      print_divider();
    }

    char customKey = customKeypad.getKey();

    if (customKey == 'e') {
      btn_accept_isdown = true;
    }
    if (customKey == 'u') {
      btn_up_isdown = true;
    }
    if (customKey == 'd') {
      btn_down_isdown = true;
    }
    if (customKey == 'c') {
      btn_cancel_isdown = true;
    }

    if (btn_down_isdown)
    {
      if (sub_pos == settings_cnt) {
        sub_pos = 1;
      } else {
        sub_pos++;
      }
      update_display = true;
      btn_down_isdown = false;
    }
    if (btn_up_isdown)
    {
      if (sub_pos == 1) {
        sub_pos = settings_cnt;
      } else {
        sub_pos--;
      }
      update_display = true;
      btn_up_isdown = false;
    }

    if (btn_cancel_isdown) {
      c_page = root_menu; return;;
    }

    if (btn_accept_isdown)
    {
      switch (sub_pos)
      {
        case 1: c_page = language; return;
        case 2: c_page = voice_output; return;
        case 3: c_page = braille_output; return;
        case 4: c_page = touch_pen; return;
        case 5: c_page = power; return;
      }
    }

    while (millis() - loopstart < 25) {
      delay(2);
    }
  }
}
//language
void language_page()
{
  bool update_display = true;
  uint32_t loopstart;
  bool btn_cancel_isdown = false;
  bool btn_up_isdown = false;
  bool btn_down_isdown = false;
  bool btn_accept_isdown = false;

  uint8_t sub_pos = 1;
  while (true)
  {
    loopstart = millis();
    if (update_display)
    {
      update_display = false;
      clear_screen();
      Serial.println(F("welcome to language section "));
      print_divider();
      print_selected(1, sub_pos); Serial.println(F("english language"));
      print_selected(2, sub_pos); Serial.println(F("bangla language"));
      Serial.println();
      Serial.println();
      print_divider();
    }
    char customKey = customKeypad.getKey();

    if (customKey == 'e') {
      btn_accept_isdown = true;
    }
    if (customKey == 'u') {
      btn_up_isdown = true;
    }
    if (customKey == 'd') {
      btn_down_isdown = true;
    }
    if (customKey == 'c') {
      btn_cancel_isdown = true;
    }

    if (btn_down_isdown)
    {
      if (sub_pos == 2) {
        sub_pos = 1;
      } else {
        sub_pos++;
      }
      update_display = true;
      btn_down_isdown = false;
    }
    if (btn_up_isdown)
    {
      if (sub_pos == 1) {
        sub_pos = 2;
      } else {
        sub_pos--;
      }
      update_display = true;
      btn_up_isdown = false;
    }

    if (btn_cancel_isdown) {
      c_page = settings; return;
    }
    if (btn_accept_isdown)
    {
      switch (sub_pos)
      {
        case 1: set_data = "E000000"; return;
        case 2: set_data = "B000000"; return;
      }
    }
    while (millis() - loopstart < 25) {
      delay(2);
    }
  }
}
//voice output
void voice_output_page()
{
  bool update_display = true;
  uint32_t loopstart;
  bool btn_cancel_isdown = false;
  bool btn_up_isdown = false;
  bool btn_down_isdown = false;
  bool btn_accept_isdown = false;

  uint8_t sub_pos = 1;
  while (true)
  {
    loopstart = millis();
    if (update_display)
    {
      update_display = false;
      clear_screen();
      Serial.println(F("welcome to voice output section "));
      print_divider();
      print_selected(1, sub_pos); Serial.println(F(" voice output enable"));
      print_selected(2, sub_pos); Serial.println(F("voice output disable"));
      Serial.println();
      Serial.println();
      print_divider();
    }

    char customKey = customKeypad.getKey();

    if (customKey == 'e') {
      btn_accept_isdown = true;
    }
    if (customKey == 'u') {
      btn_up_isdown = true;
    }
    if (customKey == 'd') {
      btn_down_isdown = true;
    }
    if (customKey == 'c') {
      btn_cancel_isdown = true;
    }
    if (btn_down_isdown)
    {
      if (sub_pos == 2) {
        sub_pos = 1;
      } else {
        sub_pos++;
      }
      update_display = true;
      btn_down_isdown = false;
    }
    if (btn_up_isdown )
    {
      if (sub_pos == 1) {
        sub_pos = 2;
      } else {
        sub_pos--;
      }
      update_display = true;
      btn_up_isdown = false;
    }

    if (btn_cancel_isdown) {
      c_page = settings; return;
    }
    if (btn_accept_isdown)
    {
      switch (sub_pos)
      {
        case 1: Serial.println(F("                                  *voice output enabled"));
        case 2: Serial.println(F("                                  *voice output disabled"));
      }
    }
    while (millis() - loopstart < 25) {
      delay(2);
    }
  }
}
//braille output
void braille_output_page()
{
  bool update_display = true;
  uint32_t loopstart;
  bool btn_cancel_isdown = false;
  bool btn_up_isdown = false;
  bool btn_down_isdown = false;
  bool btn_accept_isdown = false;

  uint8_t sub_pos = 1;
  while (true)
  {
    loopstart = millis();
    if (update_display)
    {
      update_display = false;
      clear_screen();
      Serial.println(F("welcome to braille output section "));
      print_divider();
      print_selected(1, sub_pos); Serial.println(F(" braille display output enable"));
      print_selected(2, sub_pos); Serial.println(F("braille display output disable"));
      Serial.println();
      Serial.println();
      print_divider();
    }

    char customKey = customKeypad.getKey();

    if (customKey == 'e') {
      btn_accept_isdown = true;
    }
    if (customKey == 'u') {
      btn_up_isdown = true;
    }
    if (customKey == 'd') {
      btn_down_isdown = true;
    }
    if (customKey == 'c') {
      btn_cancel_isdown = true;
    }

    if (btn_down_isdown)
    {
      if (sub_pos == 2) {
        sub_pos = 1;
      } else {
        sub_pos++;
      }
      update_display = true;
      btn_down_isdown = false;
    }
    if (btn_up_isdown)
    {
      if (sub_pos == 1) {
        sub_pos = 2;
      } else {
        sub_pos--;
      }
      update_display = true;
      btn_up_isdown = false;
    }

    if (btn_cancel_isdown) {
      c_page = settings; return;
    }
    if (btn_accept_isdown)
    {
      switch (sub_pos)
      {
        case 1: Serial.println(F("                                  *braille output enabled"));
        case 2: Serial.println(F("                                  *braille output disabled"));
      }
    }
    while (millis() - loopstart < 25) {
      delay(2);
    }
  }
}
//touch pen section
void touch_pen_page()
{
  bool update_display = true;
  uint32_t loopstart;
  bool btn_cancel_isdown = false;
  bool btn_up_isdown = false;
  bool btn_down_isdown = false;
  bool btn_accept_isdown = false;

  uint8_t sub_pos = 1;
  while (true)
  {
    loopstart = millis();
    if (update_display)
    {
      update_display = false;
      clear_screen();
      Serial.println(F("welcome to touch pen section "));
      print_divider();
      print_selected(1, sub_pos); Serial.println(F(" touch pen enable"));
      print_selected(2, sub_pos); Serial.println(F("touch pen disable"));
      Serial.println();
      Serial.println();
      print_divider();
    }
    char customKey = customKeypad.getKey();

    if (customKey == 'e') {
      btn_accept_isdown = true;
    }
    if (customKey == 'u') {
      btn_up_isdown = true;
    }
    if (customKey == 'd') {
      btn_down_isdown = true;
    }
    if (customKey == 'c') {
      btn_cancel_isdown = true;
    }

    if (btn_down_isdown)
    {
      if (sub_pos == 2) {
        sub_pos = 1;
      } else {
        sub_pos++;
      }
      update_display = true;
      btn_down_isdown = false;
    }
    if (btn_up_isdown)
    {
      if (sub_pos == 1) {
        sub_pos = 2;
      } else {
        sub_pos--;
      }
      update_display = true;
      btn_up_isdown = false;
    }

    if (btn_cancel_isdown) {
      c_page = settings; return;
    }
    if (btn_accept_isdown)
    {
      switch (sub_pos)
      {
        case 1: Serial.println(F("                                  *pen input enabled"));
        case 2: Serial.println(F("                                  *pen input disabled"));
      }
    }
    while (millis() - loopstart < 25) {
      delay(2);
    }
  }
}
//power
void power_page()
{
  bool update_display = true;
  uint32_t loopstart;
  bool btn_cancel_isdown = false;
  bool btn_up_isdown = false;
  bool btn_down_isdown = false;
  bool btn_accept_isdown = false;

  uint8_t sub_pos = 1;
  while (true)
  {
    loopstart = millis();
    if (update_display)
    {
      update_display = false;
      clear_screen();
      Serial.println(F("welcome power section "));
      print_divider();
      print_selected(1, sub_pos); Serial.println(F(" power off"));
      print_selected(2, sub_pos); Serial.println(F("restart"));
      Serial.println();
      Serial.println();
      print_divider();
    }
    char customKey = customKeypad.getKey();

    if (customKey == 'e') {
      btn_accept_isdown = true;
    }
    if (customKey == 'u') {
      btn_up_isdown = true;
    }
    if (customKey == 'd') {
      btn_down_isdown = true;
    }
    if (customKey == 'c') {
      btn_cancel_isdown = true;
    }

    if (btn_down_isdown)
    {
      if (sub_pos == 2) {
        sub_pos = 1;
      } else {
        sub_pos++;
      }
      update_display = true;
      btn_down_isdown = false;
    }
    if (btn_up_isdown )
    {
      if (sub_pos == 1) {
        sub_pos = 2;
      } else {
        sub_pos--;
      }
      update_display = true;
      btn_up_isdown = false;
    }

    if (btn_cancel_isdown) {
      c_page = settings; return;
    }
    if (btn_accept_isdown)
    {
      switch (sub_pos)
      {
        case 1: Serial.println(F("                                  *power off"));
        case 2: Serial.println(F("                                  *restart"));
      }
    }
    while (millis() - loopstart < 25) {
      delay(2);
    }
  }
}

void print_selected( uint8_t x,  uint8_t y)
{
  if (x == y)Serial.print(F("->  "));
  else Serial.print(F("    "));
}

void  clear_screen()
{
  for (uint8_t i = 0; i < 100; i++)Serial.println();
}
void  print_divider()
{
  for (uint8_t i = 0; i < 20; i++)Serial.print("--");
  Serial.println();
}
String braille_input()
{
  String data = set_data;
  for (;;) {
    if (customKeypad.getKeys())
    {
      for (int i = 0; i < LIST_MAX; i++) // Scan the whole key list.
      {
        if ( customKeypad.key[i].stateChanged )   // Only find keys that have changed state.
        {
          switch (customKeypad.key[i].kstate) {  // Report active key state : IDLE, PRESSED, HOLD, or RELEASED
            case PRESSED:
              char ch = customKeypad.key[i].kchar;
              if (ch > 48 && ch < 55)
                data[((String)ch).toInt()] = '1';
              else if (customKeypad.key[i].kchar == 'e') {
                return data;
              }
              break;
          }
        }
      }
    }
  }
}
String kerneldata_to_userdata(String data)
{
  struct Point arr[10];
  arr[0].kerneldata = "B100000";
  arr[0].userdata = "A";
  arr[1].kerneldata = "B111100";
  arr[1].userdata = "P";
  arr[2].kerneldata = "B100110";
  arr[2].userdata = "D";
  arr[3].kerneldata = "B101100";
  arr[3].userdata = "M";
  arr[4].kerneldata = "B000000";
  arr[4].userdata = " ";
  arr[5].kerneldata = "B010100";
  arr[5].userdata = "I";
  arr[6].kerneldata = "E000001";
  arr[6].userdata = "E";
  for (int i = 0; i < 10; i++)
  {
    if (data.compareTo(arr[i].kerneldata) == 0)
    {
      //if(arr[i].userdata!="B000000")
      return arr[i].userdata;
    }
  }
}
String userdata_to_kerneldata(String data)
{
  struct Point arr[10];
  arr[0].kerneldata = "B100000";
  arr[0].userdata = "A";
  arr[1].kerneldata = "B111100";
  arr[1].userdata = "P";
  arr[2].kerneldata = "B100110";
  arr[2].userdata = "D";
  arr[3].kerneldata = "B101100";
  arr[3].userdata = "M";
  arr[4].kerneldata = "B000000";
  arr[4].userdata = " ";
  arr[5].kerneldata = "B010100";
  arr[5].userdata = "I";
  for (int i = 0; i < 10; i++)
  {
    if (data.compareTo(arr[i].userdata) == 0)
    {
      if (arr[i].kerneldata != "B000000")
        return arr[i].kerneldata;
    }
  }
}

void readFile(fs::FS &fs, const char * path) {
  Serial.printf("Reading file: %s\n", path);

  File file = fs.open(path);
  if (!file) {
    Serial.println("Failed to open file for reading");
    return;
  }

  Serial.print("Read from file: ");
  while (file.available()) {
    Serial.write(file.read());
  }
  file.close();
}

void writeFile(fs::FS &fs, const char * path, String message) {
  Serial.printf("Writing file: %s\n", path);

  File file = fs.open(path, FILE_WRITE);
  if (!file) {
    Serial.println("Failed to open file for writing");
    return;
  }
  if (file.print(message)) {
    Serial.println("File written");
  } else {
    Serial.println("Write failed");
  }
  file.close();
}

void appendFile(fs::FS &fs, const char * path, String message) {
  File file = fs.open(path, FILE_APPEND);
  if (!file) {
    Serial.println("Failed to open file for appending");
    return;
  }
  if (file.print(message)) {
    Serial.println("Message appended");
  } else {
    Serial.println("Append failed");
  }
  file.close();
}

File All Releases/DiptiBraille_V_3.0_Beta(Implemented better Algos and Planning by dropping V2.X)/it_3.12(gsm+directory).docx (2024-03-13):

#include "FS.h"

#include "SD.h"

#include "SPI.h"

#include <Keypad.h>

#include <WiFi.h>

#include "Audio.h"

const byte ROWS = 4;

const byte COLS = 4;

char hexaKeys[ROWS][COLS] = {

{ '1', '4', 's', 'e' },

{ '2', '5', 'n', 'u' },

{ '3', '6', 'C', 'c' },

{ '*', 'b', '#', 'd' }

};

byte rowPins[ROWS] = { 35, 36, 37, 38 };

byte colPins[COLS] = { 39, 40, 41, 42 }; // 18-sck, 5-cs, 23-mosi, 19-miso for sd

Keypad customKeypad = Keypad(makeKeymap(hexaKeys), rowPins, colPins, ROWS, COLS);

#define SD_CS 10

#define SPI_MOSI 11

#define SPI_MISO 13

#define SPI_SCK 12

// Digital I/O used

#define I2S_DOUT 6

#define I2S_BCLK 5

#define I2S_LRC 4

Audio audio;

struct audioMessage {

uint8_t cmd;

const char* txt;

uint32_t value;

uint32_t ret;

const char* lang;

} audioTxMessage, audioRxMessage;

enum : uint8_t { SET_VOLUME,

GET_VOLUME,

CONNECTTOHOST,

CONNECTTOSD,

CONNECTTOSPEECH,

GET_AUDIOSTATUS };

QueueHandle_t audioSetQueue = NULL;

QueueHandle_t audioGetQueue = NULL;

void CreateQueues() {

audioSetQueue = xQueueCreate(10, sizeof(struct audioMessage));

audioGetQueue = xQueueCreate(10, sizeof(struct audioMessage));

}

struct language {

char userdata;

String kerneldata;

};

language eng[] = {

{ ' ', "E000000" },

{ '!', "E011101" },

{ '\"', "E000010" },

{ '#', "E001111" },

{ '$', "E110101" },

{ '%', "E100101" },

{ '&', "E111101" },

{ '\'', "E001000" },

{ '(', "E111011" },

{ ')', "E011111" },

{ '*', "E100001" },

{ '+', "E001101" },

{ ',', "E000001" },

{ '-', "E001001" },

{ '.', "E000101" },

{ '/', "E001100" },

{ '0', "E001011" },

{ '1', "E010000" },

{ '2', "E011000" },

{ '3', "E010010" },

{ '4', "E010011" },

{ '5', "E010001" },

{ '6', "E011010" },

{ '7', "E011011" },

{ '8', "E011001" },

{ '9', "E001010" },

{ ':', "E100011" },

{ ';', "E000011" },

{ '<', "E110001" },

{ '=', "E111111" },

{ '>', "E001110" },

{ '?', "E100111" },

{ '@', "E000100" },

{ 'A', "E100000" },

{ 'B', "E110000" },

{ 'C', "E100100" },

{ 'D', "E100110" },

{ 'E', "E100010" },

{ 'F', "E110100" },

{ 'G', "E110110" },

{ 'H', "E110010" },

{ 'I', "E010100" },

{ 'J', "E010110" },

{ 'K', "E101000" },

{ 'L', "E111000" },

{ 'M', "E101100" },

{ 'N', "E101010" },

{ 'P', "E111100" },

{ 'Q', "E111110" },

{ 'R', "E111010" },

{ 'S', "E011100" },

{ 'T', "E011110" },

{ 'U', "E101001" },

{ 'V', "E111001" },

{ 'W', "E010111" },

{ 'X', "E101101" },

{ 'Y', "E101111" },

{ 'Z', "E101011" },

{ '[', "E010101" },

{ '\\', "E110011" },

{ ']', "E110111" },

{ '^', "E000110" },

{ '_', "E000111" }

};

#define root_menu_cnt 7

#define write_f_cnt 3

#define practice_writing_cnt 3

#define learn_writing_cnt 3

#define read_f_cnt 3

#define practice_reading_cnt 3

#define learn_reading_cnt 3

#define audio_book_cnt 3

#define calculator_cnt 4

#define wireless_cnt 2

#define settings_cnt 5

String set_data = "E000000", s;

String dataa, buff, phone_number;

const char* ssid = "Sahanaz";

const char* password = "2024bubt";

bool capslock = false;

bool numlock = false;

bool btn_cancel_isdown = false;

bool btn_up_isdown = false;

bool btn_down_isdown = false;

bool btn_accept_isdown = false;

bool btn_backspace_isdown = false;

bool ctrl= false;

enum pagetype { root_menu,

write_f,

read_f,

audio_book,

calculator,

wireless,

sim,

settings,

doc_writing,

practice_writing,

learn_writing,

practice_alphabet_writing,

practice_number_writing,

practice_specialcharecter_writing,

learn_alphabet_writing,

learn_number_writing,

learn_specialcharecter_writing,

doc_reading,

practice_reading,

learn_reading,

practice_alphabet_reading,

practice_number_reading,

practice_specialcharecter_reading,

learn_alphabet_reading,

learn_number_reading,

learn_specialcharecter_reading,

bengali_book,

english_book,

math_book,

addition,

subtraction,

multiplication,

division,

wifi,

bluetooth,

call,

message,

language,

voice_output,

braille_output,

touch_pen,

power };

enum pagetype c_page = root_menu;

void setup() {

pinMode(SD_CS, OUTPUT);

digitalWrite(SD_CS, HIGH);

SPI.begin(SPI_SCK, SPI_MISO, SPI_MOSI);

SPI.setFrequency(1000000);

Serial.begin(115200);

WiFi.begin(ssid, password);

SD.begin(SD_CS);

if (!SD.begin()) {

Serial.println("Card Mount Failed");

return;

}

uint8_t cardType = SD.cardType();

if (cardType == CARD_NONE) {

Serial.println("No SD card attached");

return;

}

if (cardType == CARD_MMC) {

Serial.println("MMC");

} else if (cardType == CARD_SD) {

Serial.println("SDSC");

} else if (cardType == CARD_SDHC) {

Serial.println("SDHC");

} else {

Serial.println("UNKNOWN");

}

// writeFile(SD, "/text.txt", " ");

if (!SD.exists("/text.txt")) {

Serial.println("new file");

writeFile(SD, "/text.txt", " ");

}

Serial.printf("Total space: %lluMB\n", SD.totalBytes() / (1024 * 1024));

Serial.printf("Used space: %lluMB\n", SD.usedBytes() / (1024 * 1024));

audioInit();

log_i("current volume is: %d", audioGetVolume());

}

void loop() {

switch (c_page) {

//root

case root_menu: root_menu_page(); break;

case write_f: write_f_page(); break;

case read_f: read_f_page(); break;

case audio_book: audio_book_page(); break;

case calculator: calculator_page(); break;

case wireless: wireless_page(); break;

case sim: sim_page(); break;

case settings: settings_page(); break;

//write

case doc_writing: doc_writing_page(); break; //write to text file

case practice_writing: practice_writing_page(); break;

case learn_writing: learn_writing_page(); break;

//practice write

case practice_alphabet_writing: practice_alphabet_writing_page(); break;

case practice_number_writing: practice_number_writing_page(); break;

case practice_specialcharecter_writing: practice_specialcharecter_writing_page(); break;

//learn write

case learn_alphabet_writing: learn_alphabet_writing_page(); break;

case learn_number_writing: learn_number_writing_page(); break;

case learn_specialcharecter_writing: learn_specialcharecter_writing_page(); break;

//read

case doc_reading: doc_reading_page(); break; //read to text file

case practice_reading: practice_reading_page(); break;

case learn_reading: learn_reading_page(); break;

//practice read

case practice_alphabet_reading: practice_alphabet_reading_page(); break;

case practice_number_reading: practice_number_reading_page(); break;

case practice_specialcharecter_reading: practice_specialcharecter_reading_page(); break;

//learn read

case learn_alphabet_reading: learn_alphabet_reading_page(); break;

case learn_number_reading: learn_number_reading_page(); break;

case learn_specialcharecter_reading: learn_specialcharecter_reading_page(); break;

//audio book

case bengali_book: bengali_book_page(); break;

case english_book: english_book_page(); break;

case math_book: math_book_page(); break;

//calculator

case addition: addition_page(); break;

case subtraction: subtraction_page(); break;

case multiplication: multiplication_page(); break;

case division: division_page(); break;

//wireless

case wifi: wifi_page(); break;

case bluetooth: bluetooth_page(); break;

//sim

case call: call_page(); break;

case message: message_page(); break;

//settings

case language: language_page(); break;

case voice_output: voice_output_page(); break;

case braille_output: braille_output_page(); break;

case touch_pen: touch_pen_page(); break;

case power: power_page(); break;

}

}

//root menu

void root_menu_page(void) {

btn_up_isdown = false;

btn_down_isdown = false;

btn_accept_isdown = false;

bool update_display = true;

uint32_t loopstart;

uint8_t sub_pos = 1;

while (true) {

loopstart = millis();

if (update_display) {

update_display = false;

clear_screen();

Serial.println(F(" welcome to root menu"));

//audioConnecttoSD("voice_over/root_menu.mp3");

print_divider();

print_selected(1, sub_pos);

Serial.println(F("write"));

print_selected(2, sub_pos);

Serial.println(F("read"));

print_selected(3, sub_pos);

Serial.println(F("audio book"));

print_selected(4, sub_pos);

Serial.println(F("calculator"));

print_selected(5, sub_pos);

Serial.println(F("wireless"));

print_selected(6, sub_pos);

Serial.println(F("sim"));

print_selected(7, sub_pos);

Serial.println(F("settings"));

Serial.println();

Serial.println();

print_divider();

if (menu_selected(1, sub_pos)) {

audioConnecttoSD("C/menu/eng/write.mp3");

} else if (menu_selected(2, sub_pos)) //C/en/alp/A.mp3

{

audioConnecttoSD("C/menu/eng/read.mp3");

} else if (menu_selected(3, sub_pos)) {

audioConnecttoSD("C/menu/eng/audio_book.mp3");

}

if (menu_selected(4, sub_pos)) {

audioConnecttoSD("C/menu/eng/calculator.mp3");

} else if (menu_selected(5, sub_pos)) //C/en/alp/A.mp3

{

audioConnecttoSD("C/menu/eng/wireless.mp3");

} else if (menu_selected(6, sub_pos)) {

audioConnecttoSD("C/menu/eng/sim.mp3");

} else if (menu_selected(7, sub_pos)) {

audioConnecttoSD("C/menu/eng/settings.mp3");

}

}

keypress_detect();

if (btn_down_isdown) {

if (sub_pos == root_menu_cnt) {

sub_pos = 1;

} else {

sub_pos++;

}

update_display = true;

btn_down_isdown = false;

}

if (btn_up_isdown) {

if (sub_pos == 1) {

sub_pos = root_menu_cnt;

} else {

sub_pos--;

}

update_display = true;

btn_up_isdown = false;

}

if (btn_accept_isdown) {

switch (sub_pos) {

case 1: c_page = write_f; return;

case 2: c_page = read_f; return;

case 3: c_page = audio_book; return;

case 4: c_page = calculator; return;

case 5: c_page = wireless; return;

case 6: c_page = sim; return;

case 7: c_page = settings; return;

}

}

while (millis() - loopstart < 25) {

delay(2);

}

}

}

//write section

void write_f_page(void) {

btn_cancel_isdown = false;

btn_up_isdown = false;

btn_down_isdown = false;

btn_accept_isdown = false;

bool update_display = true;

uint32_t loopstart;

uint8_t sub_pos = 1;

while (true) {

loopstart = millis();

if (update_display) {

update_display = false;

clear_screen();

Serial.println(F(" write "));

print_divider();

print_selected(1, sub_pos);

Serial.println(F("doc writing"));

print_selected(2, sub_pos);

Serial.println(F("practice writing"));

print_selected(3, sub_pos);

Serial.println(F("learn writing"));

Serial.println();

Serial.println();

print_divider();

if (menu_selected(1, sub_pos)) {

audioConnecttoSD("C/menu/eng/document_writing.mp3");

} else if (menu_selected(2, sub_pos)) //C/en/alp/A.mp3

{

audioConnecttoSD("C/menu/eng/practice_writing.mp3");

} else if (menu_selected(3, sub_pos)) {

audioConnecttoSD("C/menu/eng/learn_writing.mp3");

}

}

keypress_detect();

if (btn_down_isdown) {

if (sub_pos == write_f_cnt) {

sub_pos = 1;

} else {

sub_pos++;

}

update_display = true;

btn_down_isdown = false;

}

if (btn_up_isdown) {

if (sub_pos == 1) {

sub_pos = write_f_cnt;

} else {

sub_pos--;

}

update_display = true;

btn_up_isdown = false;

}

if (btn_cancel_isdown) {

c_page = root_menu;

return;

;

}

if (btn_accept_isdown) {

switch (sub_pos) {

case 1: c_page = doc_writing; return;

case 2: c_page = practice_writing; return;

case 3: c_page = learn_writing; return;

}

}

while (millis() - loopstart < 25) {

delay(2);

}

}

}

// doc writing section

void doc_writing_page(void) {

btn_cancel_isdown = false;

btn_accept_isdown = false;

bool update_display = true;

uint32_t loopstart;

while (true) {

loopstart = millis();

if (update_display) {

update_display = false;

clear_screen();

Serial.println(F(" doc writing "));

print_divider();

print_selected(1, 1);

Serial.println(F("write to text file"));

Serial.println();

print_divider();

}

keypress_detect();

if (btn_accept_isdown) {

String st = braille_input();

char udata = kerneldata_to_userdata(st);

Serial.println(udata);

if (numlock && numlock_f(udata)) appendFile(SD, "/text.txt", (String)(udata));

if (!numlock) {

if (!capslock && (int)udata > 64 && (int)udata < 92) {

udata = (int)udata + 32;

}

appendFile(SD, "/text.txt", (String)(udata));

}

btn_accept_isdown = false;

}

if (btn_backspace_isdown) {

read_for_backspace(SD, "/text.txt");

int length = s.length();

s[length - 1] = '\0';

Serial.println(s);

writeFile(SD, "/text.txt", s);

btn_backspace_isdown = false;

}

if (btn_cancel_isdown) {

c_page = write_f;

return;

}

while (millis() - loopstart < 25) {

delay(2);

}

}

}

//practice writing section

void practice_writing_page(void) {

btn_cancel_isdown = false;

btn_up_isdown = false;

btn_down_isdown = false;

btn_accept_isdown = false;

bool update_display = true;

uint32_t loopstart;

uint8_t sub_pos = 1;

while (true) {

loopstart = millis();

if (update_display) {

update_display = false;

clear_screen();

Serial.println(F(" practice writing "));

print_divider();

print_selected(1, sub_pos);

Serial.println(F("practice alphabet writing"));

print_selected(2, sub_pos);

Serial.println(F("practice number writing"));

print_selected(3, sub_pos);

Serial.println(F("practice special charecter writing"));

Serial.println();

Serial.println();

print_divider();

if (menu_selected(1, sub_pos)) {

audioConnecttoSD("C/menu/eng/practice_alphabet_writing.mp3");

} else if (menu_selected(2, sub_pos)) //C/en/alp/A.mp3

{

audioConnecttoSD("C/menu/eng/practice_number_writing.mp3");

} else if (menu_selected(3, sub_pos)) {

audioConnecttoSD("C/menu/eng/practice_special_character_writing.mp3");

}

}

keypress_detect();

if (btn_down_isdown) {

if (sub_pos == practice_writing_cnt) {

sub_pos = 1;

} else {

sub_pos++;

}

update_display = true;

btn_down_isdown = false;

}

if (btn_up_isdown) {

if (sub_pos == 1) {

sub_pos = practice_writing_cnt;

} else {

sub_pos--;

}

update_display = true;

btn_up_isdown = false;

}

if (btn_cancel_isdown) {

c_page = write_f;

return;

}

if (btn_accept_isdown) {

switch (sub_pos) {

case 1: c_page = practice_alphabet_writing; return;

case 2: c_page = practice_number_writing; return;

case 3: c_page = practice_specialcharecter_writing; return;

}

}

while (millis() - loopstart < 25) {

delay(2);

}

}

}

//practice alphabet writing

void practice_alphabet_writing_page(void) {

btn_cancel_isdown = false;

btn_accept_isdown = false;

bool update_display = true;

uint32_t loopstart;

while (true) {

loopstart = millis();

if (update_display) {

update_display = false;

clear_screen();

print_divider();

print_selected(1, 1);

Serial.println(F("practice alphabet writing"));

Serial.println();

print_divider();

}

keypress_detect();

if (btn_cancel_isdown) {

c_page = practice_writing;

return;

}

while (millis() - loopstart < 25) {

delay(2);

}

}

}

//practice number writing

void practice_number_writing_page(void) {

btn_cancel_isdown = false;

btn_accept_isdown = false;

bool update_display = true;

uint32_t loopstart;

while (true) {

loopstart = millis();

if (update_display) {

update_display = false;

clear_screen();

print_divider();

print_selected(1, 1);

Serial.println(F("practice number writing"));

Serial.println();

print_divider();

}

keypress_detect();

if (btn_cancel_isdown) {

c_page = practice_writing;

return;

}

while (millis() - loopstart < 25) {

delay(2);

}

}

}

//practice special charecter writing

void practice_specialcharecter_writing_page(void) {

btn_cancel_isdown = false;

btn_accept_isdown = false;

bool update_display = true;

uint32_t loopstart;

while (true) {

loopstart = millis();

if (update_display) {

update_display = false;

clear_screen();

print_divider();

print_selected(1, 1);

Serial.println(F("practice special charecter writing"));

Serial.println();

print_divider();

}

keypress_detect();

if (btn_cancel_isdown) {

c_page = practice_writing;

return;

}

while (millis() - loopstart < 25) {

delay(2);

}

}

}

//learn writing section

void learn_writing_page(void) {

btn_cancel_isdown = false;

btn_up_isdown = false;

btn_down_isdown = false;

btn_accept_isdown = false;

bool update_display = true;

uint32_t loopstart;

uint8_t sub_pos = 1;

while (true) {

loopstart = millis();

if (update_display) {

update_display = false;

clear_screen();

Serial.println(F(" learn writing "));

print_divider();

print_selected(1, sub_pos);

Serial.println(F("learn alphabet writing"));

print_selected(2, sub_pos);

Serial.println(F("learn number writing"));

print_selected(3, sub_pos);

Serial.println(F("learn special charecter writing"));

Serial.println();

Serial.println();

print_divider();

if (menu_selected(1, sub_pos)) {

audioConnecttoSD("C/menu/eng/learn_alphabet_writing.mp3");

} else if (menu_selected(2, sub_pos)) //C/en/alp/A.mp3

{

audioConnecttoSD("C/menu/eng/learn_number_writing.mp3");

} else if (menu_selected(3, sub_pos)) {

audioConnecttoSD("C/menu/eng/learn_special_character_writing.mp3");

}

}

keypress_detect();

if (btn_down_isdown) {

if (sub_pos == learn_writing_cnt) {

sub_pos = 1;

} else {

sub_pos++;

}

update_display = true;

btn_down_isdown = false;

}

if (btn_up_isdown) {

if (sub_pos == 1) {

sub_pos = learn_writing_cnt;

} else {

sub_pos--;

}

update_display = true;

btn_up_isdown = false;

}

if (btn_cancel_isdown) {

c_page = write_f;

return;

}

if (btn_accept_isdown) {

switch (sub_pos) {

case 1: c_page = learn_alphabet_writing; return;

case 2: c_page = learn_number_writing; return;

case 3: c_page = learn_specialcharecter_writing; return;

}

}

while (millis() - loopstart < 25) {

delay(2);

}

}

}

//learn alphabet writing

void learn_alphabet_writing_page(void) {

btn_cancel_isdown = false;

btn_accept_isdown = false;

bool update_display = true;

uint32_t loopstart;

while (true) {

loopstart = millis();

if (update_display) {

update_display = false;

clear_screen();

print_divider();

print_selected(1, 1);

Serial.println(F("learn alphabet writing"));

Serial.println();

print_divider();

}

keypress_detect();

if (btn_cancel_isdown) {

c_page = learn_writing;

return;

}

while (millis() - loopstart < 25) {

delay(2);

}

}

}

//learn number writing

void learn_number_writing_page(void) {

btn_cancel_isdown = false;

btn_accept_isdown = false;

bool update_display = true;

uint32_t loopstart;

while (true) {

loopstart = millis();

if (update_display) {

update_display = false;

clear_screen();

print_divider();

print_selected(1, 1);

Serial.println(F("learn number writing"));

Serial.println();

print_divider();

}

keypress_detect();

if (btn_cancel_isdown) {

c_page = learn_writing;

return;

}

while (millis() - loopstart < 25) {

delay(2);

}

}

}

//learn special charecter writing

void learn_specialcharecter_writing_page(void) {

btn_cancel_isdown = false;

btn_accept_isdown = false;

bool update_display = true;

uint32_t loopstart;

while (true) {

loopstart = millis();

if (update_display) {

update_display = false;

clear_screen();

print_divider();

print_selected(1, 1);

Serial.println(F("learn special charecter writing"));

Serial.println();

print_divider();

}

keypress_detect();

if (btn_cancel_isdown) {

c_page = learn_writing;

return;

}

while (millis() - loopstart < 25) {

delay(2);

}

}

}

//read

void read_f_page(void) {

btn_cancel_isdown = false;

btn_up_isdown = false;

btn_down_isdown = false;

btn_accept_isdown = false;

bool update_display = true;

uint32_t loopstart;

uint8_t sub_pos = 1;

while (true) {

loopstart = millis();

if (update_display) {

update_display = false;

clear_screen();

Serial.println(F("reading "));

print_divider();

print_selected(1, sub_pos);

Serial.println(F("doc reading"));

print_selected(2, sub_pos);

Serial.println(F("practice reading"));

print_selected(3, sub_pos);

Serial.println(F("learn reading"));

Serial.println();

Serial.println();

print_divider();

if (menu_selected(1, sub_pos)) {

audioConnecttoSD("C/menu/eng/document_reading.mp3");

} else if (menu_selected(2, sub_pos)) //C/en/alp/A.mp3

{

audioConnecttoSD("C/menu/eng/practice_reading.mp3");

} else if (menu_selected(3, sub_pos)) {

audioConnecttoSD("C/menu/eng/learn_reading.mp3");

}

}

keypress_detect();

if (btn_down_isdown) {

if (sub_pos == read_f_cnt) {

sub_pos = 1;

} else {

sub_pos++;

}

update_display = true;

btn_down_isdown = false;

}

if (btn_up_isdown) {

if (sub_pos == 1) {

sub_pos = read_f_cnt;

} else {

sub_pos--;

}

update_display = true;

btn_up_isdown = false;

}

if (btn_cancel_isdown) {

c_page = root_menu;

return;

}

if (btn_accept_isdown) {

switch (sub_pos) {

case 1: c_page = doc_reading; return;

case 2: c_page = practice_reading; return;

case 3: c_page = learn_reading; return;

}

}

while (millis() - loopstart < 25) {

delay(2);

}

}

}

// doc reading section

void doc_reading_page(void) {

btn_cancel_isdown = false;

btn_accept_isdown = false;

bool update_display = true;

uint32_t loopstart;

while (true) {

loopstart = millis();

if (update_display) {

update_display = false;

clear_screen();

Serial.println(F(" doc reading "));

print_divider();

print_selected(1, 1);

Serial.println(F("read to text file"));

Serial.println();

print_divider();

}

keypress_detect();

if (btn_cancel_isdown) {

c_page = read_f;

return;

}

if (btn_accept_isdown) {

readFile(SD, "/text.txt");

btn_accept_isdown = false;

}

while (millis() - loopstart < 25) {

delay(2);

}

}

}

//practice reading section

void practice_reading_page(void) {

btn_cancel_isdown = false;

btn_accept_isdown = false;

bool update_display = true;

uint32_t loopstart;

uint8_t sub_pos = 1;

while (true) {

loopstart = millis();

if (update_display) {

update_display = false;

clear_screen();

Serial.println(F(" practice reading "));

print_divider();

print_selected(1, sub_pos);

Serial.println(F("practice alphabet reading"));

print_selected(2, sub_pos);

Serial.println(F("practice number reading"));

print_selected(3, sub_pos);

Serial.println(F("practice special charecter reading"));

Serial.println();

Serial.println();

print_divider();

if (menu_selected(1, sub_pos)) {

audioConnecttoSD("C/menu/eng/practice_alphabet_reading.mp3");

} else if (menu_selected(2, sub_pos)) //C/en/alp/A.mp3

{

audioConnecttoSD("C/menu/eng/practice_number_reading.mp3");

} else if (menu_selected(3, sub_pos)) {

audioConnecttoSD("C/menu/eng/practice_special_character_reading.mp3");

}

}

keypress_detect();

if (btn_down_isdown) {

if (sub_pos == practice_reading_cnt) {

sub_pos = 1;

} else {

sub_pos++;

}

update_display = true;

btn_down_isdown = false;

}

if (btn_up_isdown) {

if (sub_pos == 1) {

sub_pos = practice_reading_cnt;

} else {

sub_pos--;

}

update_display = true;

btn_up_isdown = false;

}

if (btn_cancel_isdown) {

c_page = read_f;

return;

}

if (btn_accept_isdown) {

switch (sub_pos) {

case 1: c_page = practice_alphabet_reading; return;

case 2: c_page = practice_number_reading; return;

case 3: c_page = practice_specialcharecter_reading; return;

}

}

while (millis() - loopstart < 25) {

delay(2);

}

}

}

//practice alphabet reading

void practice_alphabet_reading_page(void) {

btn_cancel_isdown = false;

btn_accept_isdown = false;

bool update_display = true;

uint32_t loopstart;

while (true) {

loopstart = millis();

if (update_display) {

update_display = false;

clear_screen();

print_divider();

print_selected(1, 1);

Serial.println(F("practice alphabet reading"));

Serial.println();

print_divider();

}

keypress_detect();

if (btn_cancel_isdown) {

c_page = practice_reading;

return;

}

while (millis() - loopstart < 25) {

delay(2);

}

}

}

//practice number reading

void practice_number_reading_page(void) {

btn_cancel_isdown = false;

btn_accept_isdown = false;

bool update_display = true;

uint32_t loopstart;

while (true) {

loopstart = millis();

if (update_display) {

update_display = false;

clear_screen();

print_divider();

print_selected(1, 1);

Serial.println(F("practice number reading"));

Serial.println();

print_divider();

}

keypress_detect();

if (btn_cancel_isdown) {

c_page = practice_reading;

return;

}

while (millis() - loopstart < 25) {

delay(2);

}

}

}

//practice special charecter reading

void practice_specialcharecter_reading_page(void) {

btn_cancel_isdown = false;

btn_accept_isdown = false;

bool update_display = true;

uint32_t loopstart;

while (true) {

loopstart = millis();

if (update_display) {

update_display = false;

clear_screen();

print_divider();

print_selected(1, 1);

Serial.println(F("practice special charecter reading"));

Serial.println();

print_divider();

}

keypress_detect();

if (btn_cancel_isdown) {

c_page = practice_reading;

return;

}

while (millis() - loopstart < 25) {

delay(2);

}

}

}

//learn reading section

void learn_reading_page(void) {

btn_cancel_isdown = false;

btn_up_isdown = false;

btn_down_isdown = false;

btn_accept_isdown = false;

bool update_display = true;

uint32_t loopstart;

uint8_t sub_pos = 1;

while (true) {

loopstart = millis();

if (update_display) {

update_display = false;

clear_screen();

Serial.println(F(" learn reading "));

print_divider();

print_selected(1, sub_pos);

Serial.println(F("learn alphabet reading"));

print_selected(2, sub_pos);

Serial.println(F("learn number reading"));

print_selected(3, sub_pos);

Serial.println(F("learn special charecter reading"));

Serial.println();

Serial.println();

print_divider();

if (menu_selected(1, sub_pos)) {

audioConnecttoSD("C/menu/eng/learn_alphabet_reading.mp3");
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

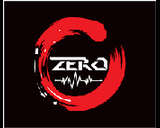
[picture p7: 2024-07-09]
image/boot_0_a.jpg

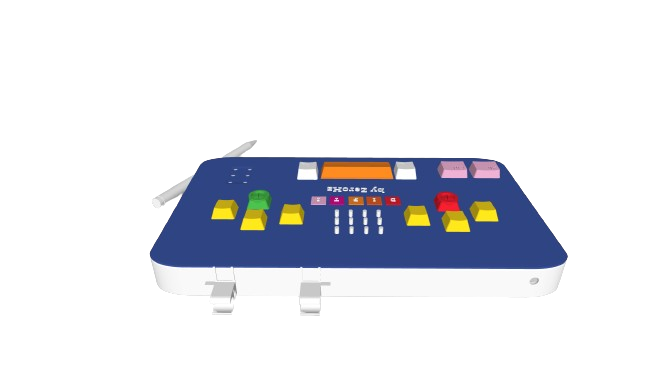
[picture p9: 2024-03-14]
image/_diptiV2_layout2_.png

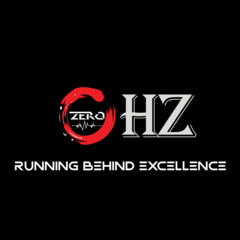
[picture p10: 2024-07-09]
image/boot0.jpg

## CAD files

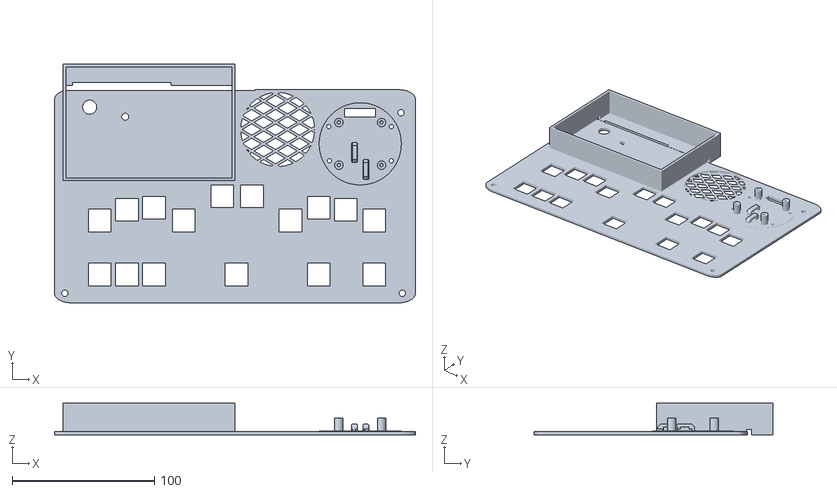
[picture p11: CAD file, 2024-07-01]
3D print/3D/PART2.stl
254.0 x 168.0 x 22.5

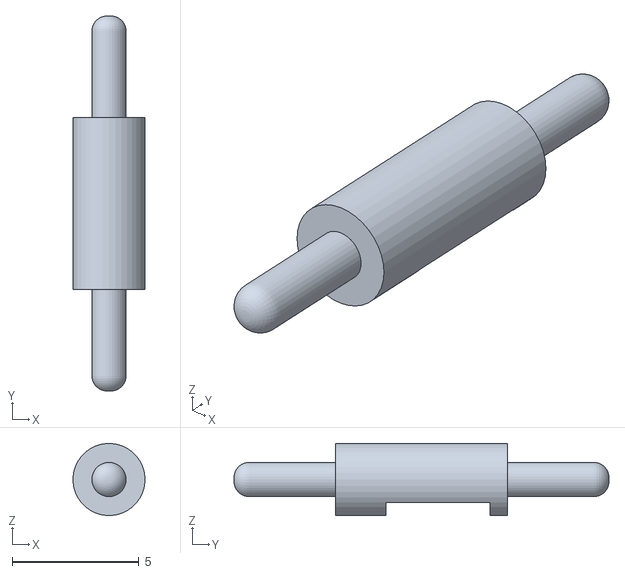
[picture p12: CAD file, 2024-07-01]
3D print/DisplayCell/MagnetHolder_v8.STL
2.85 x 14.8 x 2.85

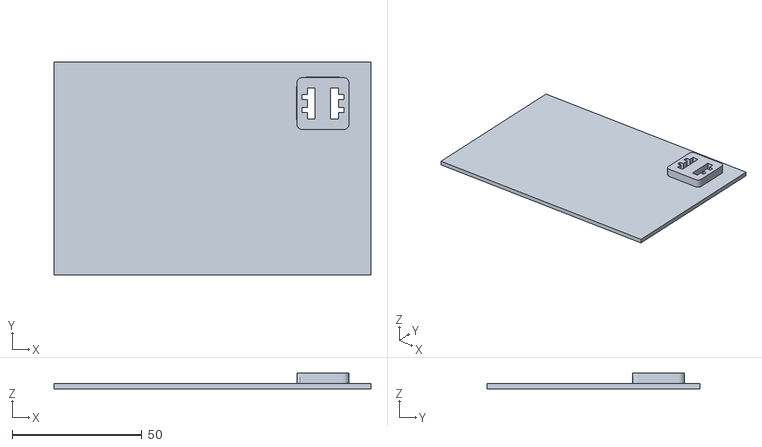
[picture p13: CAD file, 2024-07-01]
3D print/3D/PART3.stl
122.0 x 82.0 x 6.00

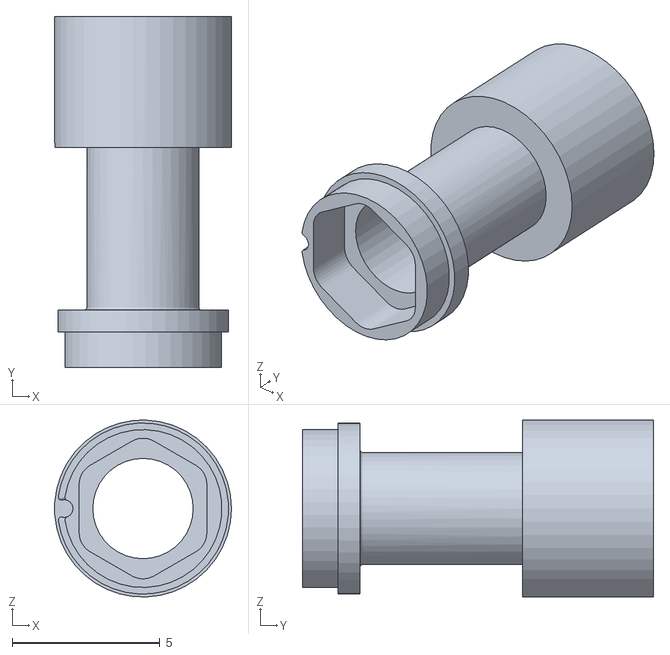
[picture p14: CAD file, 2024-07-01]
3D print/DisplayCell/CorpoV8.STL
6.00 x 11.9 x 6.00

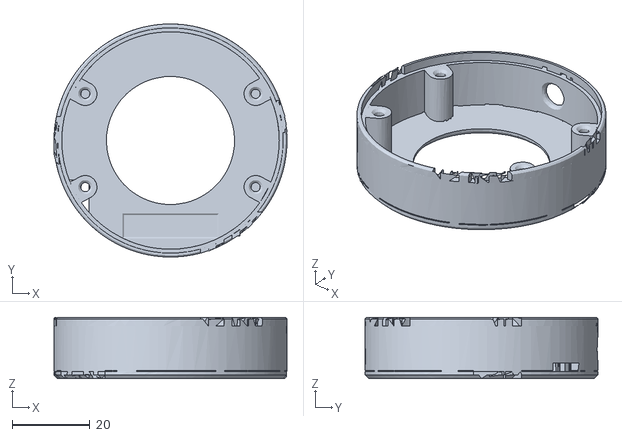
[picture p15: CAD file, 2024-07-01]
3D print/3D/PART4.stl
60.0 x 60.0 x 15.8

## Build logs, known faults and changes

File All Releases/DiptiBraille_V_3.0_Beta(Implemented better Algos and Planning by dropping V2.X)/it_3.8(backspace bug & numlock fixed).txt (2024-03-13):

#include "FS.h"
#include "SD.h"
#include "SPI.h"
#include <Keypad.h>
#include <WiFi.h>
#include "Audio.h"
const byte ROWS = 4;
const byte COLS = 4;
char hexaKeys[ROWS][COLS] = {
  {'1', '4', 's', 'e'},
  {'2', '5', 'n', 'u'},
  {'3', '6', 'C', 'c'},
  {'*', 'b', '#', 'd'}
};
byte rowPins[ROWS] = {35, 36, 37, 38};
byte colPins[COLS] =  {39, 40, 41, 42}; // 18-sck, 5-cs, 23-mosi, 19-miso for sd
Keypad customKeypad = Keypad( makeKeymap(hexaKeys), rowPins, colPins, ROWS, COLS);
#define SD_CS         10
#define SPI_MOSI      11
#define SPI_MISO      13
#define SPI_SCK       12
// Digital I/O used
#define I2S_DOUT      6
#define I2S_BCLK      5
#define I2S_LRC       4

Audio audio;
struct audioMessage{
    uint8_t     cmd;
    const char* txt;
    uint32_t    value;
    uint32_t    ret;
     const char* lang;
} audioTxMessage, audioRxMessage;

enum : uint8_t { SET_VOLUME, GET_VOLUME, CONNECTTOHOST, CONNECTTOSD, CONNECTTOSPEECH,GET_AUDIOSTATUS };

QueueHandle_t audioSetQueue = NULL;
QueueHandle_t audioGetQueue = NULL;

void CreateQueues(){
    audioSetQueue = xQueueCreate(10, sizeof(struct audioMessage));
    audioGetQueue = xQueueCreate(10, sizeof(struct audioMessage));
}
struct language {
  char userdata;
  String kerneldata;
};
language eng[] = {
  {' ', "E000000"},
  {'!', "E011101"},
  {'\"', "E000010"},
  {'#', "E001111"},
  {'$', "E110101"},
  {'%', "E100101"},
  {'&', "E111101"},
  {'\'', "E001000"},
  {'(', "E111011"},
  {')', "E011111"},
  {'*', "E100001"},
  {'+', "E001101"},
  {',', "E000001"},
  {'-', "E001001"},
  {'.', "E000101"},
  {'/', "E001100"},
  {'0', "E001011"},
  {'1', "E010000"},
  {'2', "E011000"},
  {'3', "E010010"},
  {'4', "E010011"},
  {'5', "E010001"},
  {'6', "E011010"},
  {'7', "E011011"},
  {'8', "E011001"},
  {'9', "E001010"},
  {':', "E100011"},
  {';', "E000011"},
  {'<', "E110001"},
  {'=', "E111111"},
  {'>', "E001110"},
  {'?', "E100111"},
  {'@', "E000100"},
  {'A', "E100000"},
  {'B', "E110000"},
  {'C', "E100100"},
  {'D', "E100110"},
  {'E', "E100010"},
  {'F', "E110100"},
  {'G', "E110110"},
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
};
#define root_menu_cnt 7
#define write_f_cnt 3
#define practice_writing_cnt 3
#define learn_writing_cnt 3
#define read_f_cnt 3
#define practice_reading_cnt 3
#define learn_reading_cnt 3
#define audio_book_cnt 3
#define calculator_cnt 4
#define wireless_cnt 2
#define settings_cnt 5
String set_data = "E000000",s;
String dataa,buff;
const char* ssid     = "Sahanaz";
const char* password = "2024bubt";
bool capslock = false;
bool numlock = false;
bool btn_cancel_isdown = false;
bool btn_up_isdown = false;
bool btn_down_isdown = false;
bool btn_accept_isdown = false;
bool btn_backspace_isdown = false;

enum pagetype {root_menu, write_f, read_f, audio_book, calculator, wireless, sim, settings, doc_writing, practice_writing, learn_writing, practice_alphabet_writing, practice_number_writing, practice_specialcharecter_writing, learn_alphabet_writing, learn_number_writing, learn_specialcharecter_writing,  doc_reading, practice_reading, learn_reading, practice_alphabet_reading, practice_number_reading, practice_specialcharecter_reading, learn_alphabet_reading, learn_number_reading, learn_specialcharecter_reading,  bengali_book, english_book, math_book,  addition, subtraction, multiplication, division, wifi, bluetooth, call, message, language, voice_output, braille_output, touch_pen, power};
enum pagetype c_page = root_menu;
void setup() {
  pinMode(SD_CS, OUTPUT);      digitalWrite(SD_CS, HIGH);
    SPI.begin(SPI_SCK, SPI_MISO, SPI_MOSI);
    SPI.setFrequency(1000000);
  Serial.begin(115200);
  WiFi.begin(ssid, password);
  SD.begin(SD_CS);
  if (!SD.begin()) {
    Serial.println("Card Mount Failed");
    return;
  }
  uint8_t cardType = SD.cardType();
 if (cardType == CARD_NONE) {
    Serial.println("No SD card attached");
    return;
  }
 if(cardType == CARD_MMC){
        Serial.println("MMC");
    } else if(cardType == CARD_SD){
        Serial.println("SDSC");
    } else if(cardType == CARD_SDHC){
        Serial.println("SDHC");
    } else {
        Serial.println("UNKNOWN");
    }
  // writeFile(SD, "/text.txt", " ");
  if (!SD.exists("/text.txt")) {
    Serial.println("new file");
    writeFile(SD, "/text.txt", " ");
  }
    Serial.printf("Total space: %lluMB\n", SD.totalBytes() / (1024 * 1024));
    Serial.printf("Used space: %lluMB\n", SD.usedBytes() / (1024 * 1024));
    audioInit();
    log_i("current volume is: %d", audioGetVolume());

}

void loop() {
  switch (c_page)
  {
    //root
    case root_menu: root_menu_page(); break;
    case write_f: write_f_page(); break;
    case read_f: read_f_page(); break;
    case audio_book: audio_book_page(); break;
    case calculator: calculator_page(); break;
    case wireless: wireless_page(); break;
    case sim: sim_page(); break;
    case settings: settings_page(); break;
    //write
    case doc_writing: doc_writing_page(); break;//write to text file
    case practice_writing: practice_writing_page(); break;
    case learn_writing: learn_writing_page(); break;
    //practice write
    case practice_alphabet_writing: practice_alphabet_writing_page(); break;
    case practice_number_writing: practice_number_writing_page(); break;
    case practice_specialcharecter_writing: practice_specialcharecter_writing_page(); break;
    //learn write
    case learn_alphabet_writing: learn_alphabet_writing_page(); break;
    case learn_number_writing: learn_number_writing_page(); break;
    case learn_specialcharecter_writing: learn_specialcharecter_writing_page(); break;
    //read
    case doc_reading: doc_reading_page(); break;//read to text file
    case practice_reading: practice_reading_page(); break;
    case learn_reading: learn_reading_page(); break;
    //practice read
    case practice_alphabet_reading: practice_alphabet_reading_page(); break;
    case practice_number_reading: practice_number_reading_page(); break;
    case practice_specialcharecter_reading: practice_specialcharecter_reading_page(); break;
    //learn read
    case learn_alphabet_reading: learn_alphabet_reading_page(); break;
    case learn_number_reading: learn_number_reading_page(); break;
    case learn_specialcharecter_reading: learn_specialcharecter_reading_page(); break;
    //audio book
    case bengali_book: bengali_book_page(); break;
    case english_book: english_book_page(); break;
    case math_book: math_book_page(); break;
    //calculator
    case addition: addition_page(); break;
    case subtraction: subtraction_page(); break;
    case multiplication: multiplication_page(); break;
    case division: division_page(); break;
    //wireless
    case wifi: wifi_page(); break;
    case bluetooth: bluetooth_page(); break;
    //sim
    case call: call_page(); break;
    case message: message_page(); break;
    //settings
    case language:  language_page(); break;
    case voice_output: voice_output_page(); break;
    case braille_output: braille_output_page(); break;
    case touch_pen: touch_pen_page(); break;
    case power: power_page(); break;
  }
  
}

//root menu
void root_menu_page(void)
{
  btn_up_isdown = false;
  btn_down_isdown = false;
  btn_accept_isdown = false;
  bool update_display = true;
  uint32_t loopstart;
  uint8_t sub_pos = 1;
  while (true)
  {
    loopstart = millis();
    if (update_display)
    {
      update_display = false;
      clear_screen();
      Serial.println(F("           welcome to root menu"));
      //audioConnecttoSD("voice_over/root_menu.mp3");
      print_divider();
      print_selected(1, sub_pos); Serial.println(F("write"));
      print_selected(2, sub_pos); Serial.println(F("read"));
      print_selected(3, sub_pos); Serial.println(F("audio book"));
      print_selected(4, sub_pos); Serial.println(F("calculator"));
      print_selected(5, sub_pos); Serial.println(F("wireless"));
      print_selected(6, sub_pos); Serial.println(F("sim"));
      print_selected(7, sub_pos); Serial.println(F("settings"));
      Serial.println();
      Serial.println();
      print_divider();
       if(menu_selected(1, sub_pos))
      {
audioConnecttoSD("menu/eng/write.mp3");
      }
     else if(menu_selected(2, sub_pos))//C/en/alp/A.mp3
      {
audioConnecttoSD("menu/eng/read.mp3");
      }
     else if(menu_selected(3, sub_pos))
      {
audioConnecttoSD("menu/eng/audio_book.mp3");
      }
       if(menu_selected(4, sub_pos))
      {
audioConnecttoSD("menu/eng/calculator.mp3");
      }
     else if(menu_selected(5, sub_pos))//C/en/alp/A.mp3
      {
audioConnecttoSD("menu/eng/wireless.mp3");
      }
     else if(menu_selected(6, sub_pos))
      {
audioConnecttoSD("menu/eng/sim.mp3");
      }
      else if(menu_selected(7, sub_pos))
      {
audioConnecttoSD("menu/eng/settings.mp3");
      }
    }
    keypress_detect();
    if (btn_down_isdown)
    {
      if (sub_pos == root_menu_cnt) {
        sub_pos = 1;
      } else {
        sub_pos++;
      }
      update_display = true;
      btn_down_isdown = false;
    }
    if (btn_up_isdown)
    {
      if (sub_pos == 1) {
        sub_pos = root_menu_cnt;
      } else {
        sub_pos--;
      }
      update_display = true;
      btn_up_isdown = false;
    }

    if (btn_accept_isdown)
    {
      switch (sub_pos)
      {
        case 1: c_page = write_f; return;
        case 2: c_page = read_f; return;
        case 3: c_page = audio_book; return;
        case 4: c_page = calculator; return;
        case 5: c_page = wireless; return;
        case 6: c_page = sim; return;
        case 7: c_page = settings; return;
      }
    }

    while (millis() - loopstart < 25) {
      delay(2);
    }
  }
}

//write section
void write_f_page(void)
{
  btn_cancel_isdown = false;
  btn_up_isdown = false;
  btn_down_isdown = false;
  btn_accept_isdown = false;
  bool update_display = true;
  uint32_t loopstart;
  uint8_t sub_pos = 1;
  while (true)
  {
    loopstart = millis();
    if (update_display)
    {
      update_display = false;
      clear_screen();
      Serial.println(F(" write "));
      print_divider();
      print_selected(1, sub_pos); Serial.println(F("doc writing"));
      print_selected(2, sub_pos); Serial.println(F("practice writing"));
      print_selected(3, sub_pos); Serial.println(F("learn writing"));
      Serial.println();
      Serial.println();
      print_divider();
        if(menu_selected(1, sub_pos))
      {
audioConnecttoSD("menu/eng/document_writing.mp3");
      }
     else if(menu_selected(2, sub_pos))//C/en/alp/A.mp3
      {
audioConnecttoSD("menu/eng/practice_writing.mp3");
      }
     else if(menu_selected(3, sub_pos))
      {
audioConnecttoSD("menu/eng/learn_writing.mp3");
      }
    }
    keypress_detect();
    if (btn_down_isdown)
    {
      if (sub_pos == write_f_cnt) {
        sub_pos = 1;
      } else {
        sub_pos++;
      }
      update_display = true;
      btn_down_isdown = false;
    }
    if (btn_up_isdown)
    {
      if (sub_pos == 1) {
        sub_pos = write_f_cnt;
      } else {
        sub_pos--;
      }
      update_display = true;
      btn_up_isdown = false;
    }

    if (btn_cancel_isdown) {
      c_page = root_menu; return;;
    }

    if (btn_accept_isdown)
    {
      switch (sub_pos)
      {
        case 1: c_page = doc_writing; return;
        case 2: c_page = practice_writing; return;
        case 3: c_page = learn_writing; return;
      }
    }

    while (millis() - loopstart < 25) {
      delay(2);
    }
  }
}

// doc writing section
void doc_writing_page(void)
{
  btn_cancel_isdown = false;
  btn_accept_isdown = false;
  bool update_display = true;
  uint32_t loopstart;
  while (true)
  {
    loopstart = millis();
    if (update_display)
    {
      update_display = false;
      clear_screen();
      Serial.println(F("        doc writing "));
      print_divider();
      print_selected(1, 1); Serial.println(F("write to text file"));
      Serial.println();
      print_divider();
    }
    keypress_detect();
    if (btn_accept_isdown) {
      String st = braille_input();
      char udata = kerneldata_to_userdata(st);
      Serial.println(udata);
      if(numlock&&numlock_f(udata))appendFile(SD, "/text.txt", (String)( udata));
      if(!numlock&&!capslock && (int)udata > 64 && (int)udata < 92){
        udata = (int)udata + 32;
      appendFile(SD, "/text.txt", (String)( udata));}
      btn_accept_isdown = false;
    }
    if (btn_backspace_isdown)
  {
    backspace_f(SD,"/text.txt");
     btn_backspace_isdown = false;
  }
    if (btn_cancel_isdown) {
      c_page = write_f; return;
    }
    while (millis() - loopstart < 25) {
      delay(2);
    }
  }
}
//practice writing section
void practice_writing_page(void)
{
  btn_cancel_isdown = false;
  btn_up_isdown = false;
  btn_down_isdown = false;
  btn_accept_isdown = false;
  bool update_display = true;
  uint32_t loopstart;
  uint8_t sub_pos = 1;
  while (true)
  {
    loopstart = millis();
    if (update_display)
    {
      update_display = false;
      clear_screen();
      Serial.println(F("        practice writing "));
      print_divider();
      print_selected(1, sub_pos); Serial.println(F("practice alphabet writing"));
      print_selected(2, sub_pos); Serial.println(F("practice number writing"));
      print_selected(3, sub_pos); Serial.println(F("practice special charecter writing"));
      Serial.println();
      Serial.println();
      print_divider();
        if(menu_selected(1, sub_pos))
      {
audioConnecttoSD("menu/eng/practice_alphabet_writing.mp3");
      }
     else if(menu_selected(2, sub_pos))//C/en/alp/A.mp3
      {
audioConnecttoSD("menu/eng/practice_number_writing.mp3");
      }
     else if(menu_selected(3, sub_pos))
      {
audioConnecttoSD("menu/eng/practice_special_character_writing.mp3");
      }
    }
    keypress_detect();
    if (btn_down_isdown)
    {
      if (sub_pos == practice_writing_cnt) {
        sub_pos = 1;
      } else {
        sub_pos++;
      }
      update_display = true;
      btn_down_isdown = false;
    }
    if (btn_up_isdown)
    {
      if (sub_pos == 1) {
        sub_pos = practice_writing_cnt;
      } else {
        sub_pos--;
      }
      update_display = true;
      btn_up_isdown = false;
    }

    if (btn_cancel_isdown) {
      c_page = write_f; return;
    }
    if (btn_accept_isdown)
    {
      switch (sub_pos)
      {
        case 1: c_page = practice_alphabet_writing; return;
        case 2: c_page = practice_number_writing; return;
        case 3: c_page =  practice_specialcharecter_writing; return;
      }
    }
    while (millis() - loopstart < 25) {
      delay(2);
    }
  }
}
//practice alphabet writing
void practice_alphabet_writing_page(void)
{
  btn_cancel_isdown = false;
  btn_accept_isdown = false;
  bool update_display = true;
  uint32_t loopstart;
  while (true)
  {
    loopstart = millis();
    if (update_display)
    {
      update_display = false;
      clear_screen();
      print_divider();
      print_selected(1, 1); Serial.println(F("practice alphabet writing"));
      Serial.println();
      print_divider();
    }
    keypress_detect();
    if (btn_cancel_isdown) {
      c_page = practice_writing; return;
    }
    while (millis() - loopstart < 25) {
      delay(2);
    }
  }
}
//practice number writing
void practice_number_writing_page(void)
{
  btn_cancel_isdown = false;
  btn_accept_isdown = false;
  bool update_display = true;
  uint32_t loopstart;
  while (true)
  {
    loopstart = millis();
    if (update_display)
    {
      update_display = false;
      clear_screen();
      print_divider();
      print_selected(1, 1); Serial.println(F("practice number writing"));
      Serial.println();
      print_divider();
    }
    keypress_detect();
    if (btn_cancel_isdown) {
      c_page = practice_writing; return;
    }
    while (millis() - loopstart < 25) {
      delay(2);
    }
  }
}
//practice special charecter writing
void practice_specialcharecter_writing_page(void)
{
  btn_cancel_isdown = false;
  btn_accept_isdown = false;
  bool update_display = true;
  uint32_t loopstart;
  while (true)
  {
    loopstart = millis();
    if (update_display)
    {
      update_display = false;
      clear_screen();
      print_divider();
      print_selected(1, 1); Serial.println(F("practice special charecter writing"));
      Serial.println();
      print_divider();
    }
    keypress_detect();
    if (btn_cancel_isdown) {
      c_page = practice_writing; return;
    }
    while (millis() - loopstart < 25) {
      delay(2);
    }
  }
}
//learn writing section
void learn_writing_page(void)
{
  btn_cancel_isdown = false;
  btn_up_isdown = false;
  btn_down_isdown = false;
  btn_accept_isdown = false;
  bool update_display = true;
  uint32_t loopstart;
  uint8_t sub_pos = 1;
  while (true)
  {
    loopstart = millis();
    if (update_display)
    {
      update_display = false;
      clear_screen();
      Serial.println(F("        learn writing "));
      print_divider();
      print_selected(1, sub_pos); Serial.println(F("learn alphabet writing"));
      print_selected(2, sub_pos); Serial.println(F("learn number writing"));
      print_selected(3, sub_pos); Serial.println(F("learn special charecter writing"));
      Serial.println();
      Serial.println();
      print_divider();
          if(menu_selected(1, sub_pos))
      {
audioConnecttoSD("menu/eng/learn_alphabet_writing.mp3");
      }
     else if(menu_selected(2, sub_pos))//C/en/alp/A.mp3
      {
audioConnecttoSD("menu/eng/learn_number_writing.mp3");
      }
     else if(menu_selected(3, sub_pos))
      {
audioConnecttoSD("menu/eng/learn_special_character_writing.mp3");
      }
    }
    keypress_detect();
    if (btn_down_isdown)
    {
      if (sub_pos == learn_writing_cnt) {
        sub_pos = 1;
      } else {
        sub_pos++;
      }
      update_display = true;
      btn_down_isdown = false;
    }
    if (btn_up_isdown)
    {
      if (sub_pos == 1) {
        sub_pos = learn_writing_cnt;
      } else {
        sub_pos--;
      }
      update_display = true;
      btn_up_isdown = false;
    }

    if (btn_cancel_isdown) {
      c_page = write_f; return;
    }
    if (btn_accept_isdown)
    {
      switch (sub_pos)
      {
        case 1: c_page = learn_alphabet_writing; return;
        case 2: c_page = learn_number_writing; return;
        case 3: c_page =  learn_specialcharecter_writing; return;
      }
    }

    while (millis() - loopstart < 25) {
      delay(2);
    }
  }

}
//learn alphabet writing
void learn_alphabet_writing_page(void)
{
  btn_cancel_isdown = false;
  btn_accept_isdown = false;
  bool update_display = true;
  uint32_t loopstart;
  while (true)
  {
    loopstart = millis();
    if (update_display)
    {
      update_display = false;
      clear_screen();
      print_divider();
      print_selected(1, 1); Serial.println(F("learn alphabet writing"));
      Serial.println();
      print_divider();
    }
    keypress_detect();
    if (btn_cancel_isdown) {
      c_page = learn_writing; return;
    }
    while (millis() - loopstart < 25) {
      delay(2);
    }
  }
}
//learn number writing
void learn_number_writing_page(void)
{
  btn_cancel_isdown = false;
  btn_accept_isdown = false;
  bool update_display = true;
  uint32_t loopstart;
  while (true)
  {
    loopstart = millis();
    if (update_display)
    {
      update_display = false;
      clear_screen();
      print_divider();
      print_selected(1, 1); Serial.println(F("learn number writing"));
      Serial.println();
      print_divider();
    }
    keypress_detect();
    if (btn_cancel_isdown) {
      c_page = learn_writing; return;
    }
    while (millis() - loopstart < 25) {
      delay(2);
    }
  }
}
//learn special charecter writing
void learn_specialcharecter_writing_page(void)
{
  btn_cancel_isdown = false;
  btn_accept_isdown = false;
  bool update_display = true;
  uint32_t loopstart;
  while (true)
  {
    loopstart = millis();
    if (update_display)
    {
      update_display = false;
      clear_screen();
      print_divider();
      print_selected(1, 1); Serial.println(F("learn special charecter writing"));
      Serial.println();
      print_divider();
    }
    keypress_detect();
    if (btn_cancel_isdown) {
      c_page = learn_writing; return;
    }
    while (millis() - loopstart < 25) {
      delay(2);
    }
  }
}
//read
void read_f_page(void)
{
  btn_cancel_isdown = false;
  btn_up_isdown = false;
  btn_down_isdown = false;
  btn_accept_isdown = false;
  bool update_display = true;
  uint32_t loopstart;
  uint8_t sub_pos = 1;
  while (true)
  {
    loopstart = millis();
    if (update_display)
    {
      update_display = false;
      clear_screen();
      Serial.println(F("reading "));
      print_divider();
      print_selected(1, sub_pos); Serial.println(F("doc reading"));
      print_selected(2, sub_pos); Serial.println(F("practice reading"));
      print_selected(3, sub_pos); Serial.println(F("learn reading"));
      Serial.println();
      Serial.println();
      print_divider();
           if(menu_selected(1, sub_pos))
      {
audioConnecttoSD("menu/eng/document_reading.mp3");
      }
     else if(menu_selected(2, sub_pos))//C/en/alp/A.mp3
      {
audioConnecttoSD("menu/eng/practice_reading.mp3");
      }
     else if(menu_selected(3, sub_pos))
      {
audioConnecttoSD("menu/eng/learn_reading.mp3");
      }
    }
    
    keypress_detect();
    if (btn_down_isdown)
    {
      if (sub_pos == read_f_cnt) {
        sub_pos = 1;
      } else {
        sub_pos++;
      }
      update_display = true;
      btn_down_isdown = false;
    }
    if (btn_up_isdown)
    {
      if (sub_pos == 1) {
        sub_pos = read_f_cnt;
      } else {
        sub_pos--;
      }
      update_display = true;
      btn_up_isdown = false;
    }
    if (btn_cancel_isdown) {
      c_page = root_menu; return;
    }
    if (btn_accept_isdown)
    {
      switch (sub_pos)
      {
        case 1: c_page = doc_reading; return;
        case 2: c_page = practice_reading; return;
        case 3: c_page = learn_reading; return;
      }
    }
    while (millis() - loopstart < 25) {
      delay(2);
    }
  }
}

// doc reading section
void doc_reading_page(void)
{
  btn_cancel_isdown = false;
  btn_accept_isdown = false;
  bool update_display = true;
  uint32_t loopstart;
  while (true)
  {
    loopstart = millis();
    if (update_display)
    {
      update_display = false;
      clear_screen();
      Serial.println(F("        doc reading "));
      print_divider();
      print_selected(1, 1); Serial.println(F("read to text file"));
      Serial.println();
      print_divider();
    }
    keypress_detect();
    if (btn_cancel_isdown) {
      c_page = read_f; return;
    }
    if (btn_accept_isdown)
    {
      readFile(SD, "/text.txt");
      //audioConnecttoSpeech(s.c_str(),"en");
      btn_accept_isdown = false;
    }
    while (millis() - loopstart < 25) {
      delay(2);
    }
  }
}
//practice reading section
void practice_reading_page(void)
{
  btn_cancel_isdown = false;
  btn_accept_isdown = false;
  bool update_display = true;
  uint32_t loopstart;
  uint8_t sub_pos = 1;
  while (true)
  {
    loopstart = millis();
    if (update_display)
    {
      update_display = false;
      clear_screen();
      Serial.println(F("        practice reading "));
      print_divider();
      print_selected(1, sub_pos); Serial.println(F("practice alphabet reading"));
      print_selected(2, sub_pos); Serial.println(F("practice number reading"));
      print_selected(3, sub_pos); Serial.println(F("practice special charecter reading"));
      Serial.println();
      Serial.println();
      print_divider();
              if(menu_selected(1, sub_pos))
      {
audioConnecttoSD("menu/eng/practice_alphabet_reading.mp3");
      }
     else if(menu_selected(2, sub_pos))//C/en/alp/A.mp3
      {
audioConnecttoSD("menu/eng/practice_number_reading.mp3");
      }
     else if(menu_selected(3, sub_pos))
      {
audioConnecttoSD("menu/eng/practice_special_character_reading.mp3");
      }
    }
    keypress_detect();
    if (btn_down_isdown)
    {
      if (sub_pos == practice_reading_cnt) {
        sub_pos = 1;
      } else {
        sub_pos++;
      }
      update_display = true;
      btn_down_isdown = false;
    }
    if (btn_up_isdown)
    {
      if (sub_pos == 1) {
        sub_pos = practice_reading_cnt;
      } else {
        sub_pos--;
      }
      update_display = true;
      btn_up_isdown = false;
    }

    if (btn_cancel_isdown) {
      c_page = read_f; return;
    }
    if (btn_accept_isdown)
    {
      switch (sub_pos)
      {
        case 1: c_page = practice_alphabet_reading; return;
        case 2: c_page = practice_number_reading; return;
        case 3: c_page =  practice_specialcharecter_reading; return;
      }
    }
    while (millis() - loopstart < 25) {
      delay(2);
    }
  }
}
//practice alphabet reading
void practice_alphabet_reading_page(void)
{
  btn_cancel_isdown = false;
  btn_accept_isdown = false;
  bool update_display = true;
  uint32_t loopstart;
  while (true)
  {
    loopstart = millis();
    if (update_display)
    {
      update_display = false;
      clear_screen();
      print_divider();
      print_selected(1, 1); Serial.println(F("practice alphabet reading"));
      Serial.println();
      print_divider();
    }
    keypress_detect();
    if (btn_cancel_isdown) {
      c_page = practice_reading; return;
    }
    while (millis() - loopstart < 25) {
      delay(2);
    }
  }
}
//practice number reading
void practice_number_reading_page(void)
{
  btn_cancel_isdown = false;
  btn_accept_isdown = false;
  bool update_display = true;
  uint32_t loopstart;
  while (true)
  {
    loopstart = millis();
    if (update_display)
    {
      update_display = false;
      clear_screen();
      print_divider();
      print_selected(1, 1); Serial.println(F("practice number reading"));
      Serial.println();
      print_divider();
    }
    keypress_detect();
    if (btn_cancel_isdown) {
      c_page = practice_reading; return;
    }
    while (millis() - loopstart < 25) {
      delay(2);
    }
  }
}
//practice special charecter reading
void practice_specialcharecter_reading_page(void)
{
  btn_cancel_isdown = false;
  btn_accept_isdown = false;
  bool update_display = true;
  uint32_t loopstart;
  while (true)
  {
    loopstart = millis();
    if (update_display)
    {
      update_display = false;
      clear_screen();
      print_divider();
      print_selected(1, 1); Serial.println(F("practice special charecter reading"));
      Serial.println();
      print_divider();
    }
    keypress_detect();
    if (btn_cancel_isdown) {
      c_page = practice_reading; return;
    }
    while (millis() - loopstart < 25) {
      delay(2);
    }
  }
}
//learn reading section
void learn_reading_page(void)
{
  btn_cancel_isdown = false;
  btn_up_isdown = false;
  btn_down_isdown = false;
  btn_accept_isdown = false;
  bool update_display = true;
  uint32_t loopstart;
  uint8_t sub_pos = 1;
  while (true)
  {
    loopstart = millis();
    if (update_display)
    {
      update_display = false;
      clear_screen();
      Serial.println(F("        learn reading "));
      print_divider();
      print_selected(1, sub_pos); Serial.println(F("learn alphabet reading"));
      print_selected(2, sub_pos); Serial.println(F("learn number reading"));
      print_selected(3, sub_pos); Serial.println(F("learn special charecter reading"));
      Serial.println();
      Serial.println();
      print_divider();
        if(menu_selected(1, sub_pos))
      {
audioConnecttoSD("menu/eng/learn_alphabet_reading.mp3");
      }
     else if(menu_selected(2, sub_pos))//C/en/alp/A.mp3
      {
audioConnecttoSD("menu/eng/learn_number_reading.mp3");
      }
     else if(menu_selected(3, sub_pos))
      {
audioConnecttoSD("menu/eng/learn_special_character_reading.mp3");
      }
    }
    keypress_detect();
    if (btn_down_isdown)
    {
      if (sub_pos == learn_reading_cnt) {
        sub_pos = 1;
      } else {
        sub_pos++;
      }
      update_display = true;
      btn_down_isdown = false;
    }
    if (btn_up_isdown)
    {
      if (sub_pos == 1) {
        sub_pos = learn_reading_cnt;
      } else {
        sub_pos--;
      }
      update_display = true;
      btn_up_isdown = false;
    }

    if (btn_cancel_isdown) {
      c_page = read_f; return;
    }
    if (btn_accept_isdown)
    {
      switch (sub_pos)
      {
        case 1: c_page = learn_alphabet_reading; return;
        case 2: c_page = learn_number_reading; return;
        case 3: c_page =  learn_specialcharecter_reading; return;
      }
    }

    while (millis() - loopstart < 25) {
      delay(2);
    }
  }

}
//learn alphabet reading
void learn_alphabet_reading_page(void)
{
  btn_cancel_isdown = false;
  btn_accept_isdown = false;
  bool update_display = true;
  uint32_t loopstart;
  while (true)
  {
    loopstart = millis();
    if (update_display)
    {
      update_display = false;
      clear_screen();
      print_divider();
      print_selected(1, 1); Serial.println(F("learn alphabet reading"));
      Serial.println();
      print_divider();
    }
    keypress_detect();
    if (btn_cancel_isdown) {
      c_page = learn_reading; return;
    }
    while (millis() - loopstart < 25) {
      delay(2);
    }
  }
}
//learn number reading
void learn_number_reading_page(void)
{
  btn_cancel_isdown = false;
  btn_accept_isdown = false;
  bool update_display = true;
  uint32_t loopstart;
  while (true)
  {
    loopstart = millis();
    if (update_display)
    {
      update_display = false;
      clear_screen();
      print_divider();
      print_selected(1, 1); Serial.println(F("learn number reading"));
      Serial.println();
      print_divider();
    }
    keypress_detect();
    if (btn_cancel_isdown) {
      c_page = learn_reading; return;
    }
    while (millis() - loopstart < 25) {
      delay(2);
    }
  }
}
//learn special charecter reading
void learn_specialcharecter_reading_page(void)
{
  btn_cancel_isdown = false;
  btn_accept_isdown = false;
  bool update_display = true;
  uint32_t loopstart;
  while (true)
  {
    loopstart = millis();
    if (update_display)
    {
      update_display = false;
      clear_screen();
      print_divider();
      print_selected(1, 1); Serial.println(F("learn special charecter reading"));
      Serial.println();
      print_divider();
    }
    keypress_detect();
    if (btn_cancel_isdown) {
      c_page = learn_reading; return;
    }
    while (millis() - loopstart < 25) {
      delay(2);
    }
  }
}
//audio_book
void audio_book_page(void)
{
  btn_cancel_isdown = false;
  btn_up_isdown = false;
  btn_down_isdown = false;
  btn_accept_isdown = false;
  bool update_display = true;
  uint32_t loopstart;
  uint8_t sub_pos = 1;
  while (true)
  {
    loopstart = millis();
    if (update_display)
    {
      update_display = false;
      clear_screen();
      Serial.println(F("listen audio book "));
      print_divider();
      print_selected(1, sub_pos); Serial.println(F("bengali book"));
      print_selected(2, sub_pos); Serial.println(F("english book"));
      print_selected(3, sub_pos); Serial.println(F("math book"));
      Serial.println();
      Serial.println();
      print_divider();
      if(menu_selected(1, sub_pos))
      {
audioConnecttoSD("menu/eng/bengali_book.mp3");
      }
     else if(menu_selected(2, sub_pos))//C/en/alp/A.mp3
      {
audioConnecttoSD("menu/eng/english_book.mp3");
      }
     else if(menu_selected(3, sub_pos))
      {
audioConnecttoSD("menu/eng/math_book.mp3");
      }
    }
    keypress_detect();
    if (btn_down_isdown)
    {
      if (sub_pos == audio_book_cnt) {
        sub_pos = 1;
      } else {
        sub_pos++;
      }
      update_display = true;
      btn_down_isdown = false;
    }
    if (btn_up_isdown)
    {
      if (sub_pos == 1) {
        sub_pos = audio_book_cnt;
      } else {
        sub_pos--;
      }
      update_display = true;
      btn_up_isdown = false;
    }

    if (btn_cancel_isdown) {
      c_page = root_menu; return;;
    }

    if (btn_accept_isdown)
    {
      switch (sub_pos)
      {
        case 1: c_page = bengali_book; return;
        case 2: c_page = english_book; return;
        case 3: c_page = math_book; return;
      }
    }

    while (millis() - loopstart < 25) {
      delay(2);
    }
  }
}
void bengali_book_page()
{
  btn_cancel_isdown = false;
  btn_accept_isdown = false;
  bool update_display = true;
  uint32_t loopstart;
  while (true)
  {
    loopstart = millis();
    if (update_display)
    {
      update_display = false;
      clear_screen();
      Serial.println(F("        bengali book"));
      print_divider();
      print_selected(1, 1); Serial.println(F("play bengali.wav"));
      Serial.println();
      print_divider();
    }
    keypress_detect();
    if (btn_cancel_isdown) {
      c_page = audio_book; return;
    }
    while (millis() - loopstart < 25) {
      delay(2);
    }
  }
}
void english_book_page()
{
  btn_cancel_isdown = false;
  btn_accept_isdown = false;
  bool update_display = true;
  uint32_t loopstart;
  while (true)
  {
    loopstart = millis();
    if (update_display)
    {
      update_display = false;
      clear_screen();
      Serial.println(F("        english book"));
      print_divider();
      print_selected(1, 1); Serial.println(F("play english.wav"));
      Serial.println();
      print_divider();
    }
    keypress_detect();
    if (btn_cancel_isdown) {
      audioConnecttoSD("menu/eng/stop.mp3");
      c_page = audio_book; return;
    }
 if (btn_accept_isdown) {
      audioConnecttoSD("pritom.mp3");
      btn_accept_isdown=false;
    }
    while (millis() - loopstart < 25) {
      delay(2);
    }
  }
}
void math_book_page()
{
  btn_cancel_isdown = false;
  btn_accept_isdown = false;
  bool update_display = true;
  uint32_t loopstart;
  while (true)
  {
    loopstart = millis();
    if (update_display)
    {
      update_display = false;
      clear_screen();
      Serial.println(F("        math book"));
      print_divider();
      print_selected(1, 1); Serial.println(F("play math.wav"));
      Serial.println();
      print_divider();
    }
    keypress_detect();
    if (btn_cancel_isdown) {
      c_page = audio_book; return;
    }
    while (millis() - loopstart < 25) {
      delay(2);
    }
  }
}

void calculator_page(void)
{
  btn_cancel_isdown = false;
  btn_up_isdown = false;
  btn_down_isdown = false;
  btn_accept_isdown = false;
  bool update_display = true;
  uint32_t loopstart;
  uint8_t sub_pos = 1;
  while (true)
  {
    loopstart = millis();
    if (update_display)
    {
      update_display = false;
      clear_screen();
      Serial.println(F("welcome to calculator "));
      print_divider();
      print_selected(1, sub_pos); Serial.println(F("addition"));
      print_selected(2, sub_pos); Serial.println(F("subtraction"));
      print_selected(3, sub_pos); Serial.println(F("multiplication"));
      print_selected(4, sub_pos); Serial.println(F("divison"));
      Serial.println();
      Serial.println();
      print_divider();
         if(menu_selected(1, sub_pos))
      {
audioConnecttoSD("menu/eng/addition.mp3");
      }
     else if(menu_selected(2, sub_pos))//C/en/alp/A.mp3
      {
audioConnecttoSD("menu/eng/subtraction.mp3");
      }
     else if(menu_selected(3, sub_pos))
      {
audioConnecttoSD("menu/eng/multiplication.mp3");
      }
      else if(menu_selected(4, sub_pos))
      {
audioConnecttoSD("menu/eng/division.mp3");
      }
    }
    keypress_detect();
    if (btn_down_isdown)
    {
      if (sub_pos == calculator_cnt) {
        sub_pos = 1;
      } else {
        sub_pos++;
      }
      update_display = true;
      btn_down_isdown = false;
    }
    if (btn_up_isdown)
    {
      if (sub_pos == 1) {
        sub_pos = calculator_cnt;
      } else {
        sub_pos--;
      }
      update_display = true;
      btn_up_isdown = false;
    }

    if (btn_cancel_isdown) {
      c_page = root_menu; return;;
    }

    if (btn_accept_isdown)
    {
      switch (sub_pos)
      {
        case 1: c_page = addition; return;
        case 2: c_page = subtraction; return;
        case 3: c_page = multiplication; return;
        case 4: c_page = division; return;
      }
    }

    while (millis() - loopstart < 25) {
      delay(2);
    }
  }
}
void addition_page()
{
  btn_cancel_isdown = false;
  btn_accept_isdown = false;
  bool update_display = true;
  uint32_t loopstart;
  while (true)
  {
    loopstart = millis();
    if (update_display)
    {
      update_display = false;
      clear_screen();
      Serial.println(F("        addition"));
      print_divider();
      print_selected(1, 1); Serial.println(F("A+B"));
      Serial.println();
      print_divider();
    }
    keypress_detect();
    if (btn_cancel_isdown) {
      c_page = calculator; return;
    }
    while (millis() - loopstart < 25) {
      delay(2);
    }
  }
}
void subtraction_page()
{
  btn_cancel_isdown = false;
  btn_accept_isdown = false;
  bool update_display = true;
  uint32_t loopstart;
  while (true)
  {
    loopstart = millis();
    if (update_display)
    {
      update_display = false;
      clear_screen();
      Serial.println(F("        subtraction"));
      print_divider();
      print_selected(1, 1); Serial.println(F("A-B"));
      Serial.println();
      print_divider();
    }
    keypress_detect();
    if (btn_cancel_isdown) {
      c_page = calculator; return;
    }
    while (millis() - loopstart < 25) {
      delay(2);
    }
  }
}
void multiplication_page()
{
  btn_cancel_isdown = false;
  btn_accept_isdown = false;
  bool update_display = true;
  uint32_t loopstart;
  while (true)
  {
    loopstart = millis();
    if (update_display)
    {
      update_display = false;
      clear_screen();
      Serial.println(F("        multiplication"));
      print_divider();
      print_selected(1, 1); Serial.println(F("A*B"));
      Serial.println();
      print_divider();
    }
    keypress_detect();
    if (btn_cancel_isdown) {
      c_page = calculator; return;
    }
    while (millis() - loopstart < 25) {
      delay(2);
    }
  }
}
void division_page()
{
  btn_cancel_isdown = false;
  btn_accept_isdown = false;
  bool update_display = true;
  uint32_t loopstart;
  while (true)
  {
    loopstart = millis();
    if (update_display)
    {
      update_display = false;
      clear_screen();
      Serial.println(F("        division"));
      print_divider();
      print_selected(1, 1); Serial.println(F("A/B"));
      Serial.println();
      print_divider();
    }
    keypress_detect();
    if (btn_cancel_isdown) {
      c_page = calculator; return;
    }
    while (millis() - loopstart < 25) {
      delay(2);
    }
  }
}

void wireless_page(void)
{
  btn_cancel_isdown = false;
  btn_up_isdown = false;
  btn_down_isdown = false;
  btn_accept_isdown = false;
  bool update_display = true;
  uint32_t loopstart;
  uint8_t sub_pos = 1;
  while (true)
  {
    loopstart = millis();
    if (update_display)
    {
      update_display = false;
      clear_screen();
      Serial.println(F("welcome to wireless section "));
      print_divider();
      print_selected(1, sub_pos); Serial.println(F("wifi"));
      print_selected(2, sub_pos); Serial.println(F("bluetooth"));
      Serial.println();
      Serial.println();
      print_divider();
            if(menu_selected(1, sub_pos))
      {
audioConnecttoSD("menu/eng/wifi.mp3");
      }
     else if(menu_selected(2, sub_pos))//C/en/alp/A.mp3
      {
audioConnecttoSD("menu/eng/bluetooth.mp3");
      }
    }
    keypress_detect();
    if (btn_down_isdown)
    {
      if (sub_pos == wireless_cnt) {
        sub_pos = 1;
      } else {
        sub_pos++;
      }
      update_display = true;
      btn_down_isdown = false;
    }
    if (btn_up_isdown)
    {
      if (sub_pos == 1) {
        sub_pos = wireless_cnt;
      } else {
        sub_pos--;
      }
      update_display = true;
      btn_up_isdown = false;
    }

    if (btn_cancel_isdown) {
      c_page = root_menu; return;;
    }
    if (btn_accept_isdown)
    {
      switch (sub_pos)
      {
        case 1: c_page = wifi; return;
        case 2: c_page = bluetooth; return;
      }
    }
    while (millis() - loopstart < 25) {
      delay(2);
    }
  }
}
void wifi_page()
{
  btn_cancel_isdown = false;
  btn_up_isdown = false;
  btn_down_isdown = false;
  btn_accept_isdown = false;
  bool update_display = true;
  uint32_t loopstart;
  uint8_t sub_pos = 1;
  while (true)
  {
    loopstart = millis();
    if (update_display)
    {
      update_display = false;
      clear_screen();
      Serial.println(F("welcome to wifi section "));
      print_divider();
      print_selected(1, sub_pos); Serial.println(F("enter wifi ssid"));
      print_selected(2, sub_pos); Serial.println(F("enter wifi password"));
      print_selected(3, sub_pos); Serial.println(F("press enter to set credential"));
      Serial.println();
      Serial.println();
      print_divider();
            if(menu_selected(1, sub_pos))
      {
audioConnecttoSD("menu/eng/wifi_ssid.mp3");
      }
     else if(menu_selected(2, sub_pos))//C/en/alp/A.mp3
      {
audioConnecttoSD("menu/eng/wifi_password.mp3");
      }
    }
    keypress_detect();
    if (btn_down_isdown)
    {
      if (sub_pos == 3) {
        sub_pos = 1;
      } else {
        sub_pos++;
      }
      update_display = true;
      btn_down_isdown = false;
    }
    if (btn_up_isdown)
    {
      if (sub_pos == 1) {
        sub_pos = 3;
      } else {
        sub_pos--;
      }
      update_display = true;
      btn_up_isdown = false;
    }

    if (btn_cancel_isdown) {
      c_page = wireless; return;;
    }
    if (btn_accept_isdown)
    {
      switch (sub_pos)
      {
        case 1:
          Serial.println(F("                                  enter ssid"));
          while (Serial.available() == 0) {
            String ssid = Serial.readString();

            if (ssid != NULL) {
              Serial.println(ssid);
              return;
            }

            if (btn_cancel_isdown)break;
          }

        case 2:
          Serial.println(F("                                  enter password"));
        case 3:
          Serial.println(F("                                  *set credential"));
      }
    }
    while (millis() - loopstart < 25) {
      delay(2);
    }
  }
}
void bluetooth_page()
{
  btn_cancel_isdown = false;
  btn_up_isdown = false;
  btn_down_isdown = false;
  btn_accept_isdown = false;
  bool update_display = true;
  uint32_t loopstart;
  uint8_t sub_pos = 1;
  while (true)
  {
    loopstart = millis();
    if (update_display)
    {
      update_display = false;
      clear_screen();
      Serial.println(F("welcome to bluetooth section "));
      print_divider();
      print_selected(1, sub_pos); Serial.println(F("turn on bluetooth"));
      print_selected(2, sub_pos); Serial.println(F("turn off bluetooth"));
      Serial.println();
      Serial.println();
      print_divider();
            if(menu_selected(1, sub_pos))
      {
audioConnecttoSD("menu/eng/bluetooth_on.mp3");
      }
     else if(menu_selected(2, sub_pos))//C/en/alp/A.mp3
      {
audioConnecttoSD("menu/eng/bluetooth_off.mp3");
      }
    }
    keypress_detect();
    if (btn_down_isdown)
    {
      if (sub_pos == 2) {
        sub_pos = 1;
      } else {
        sub_pos++;
      }
      update_display = true;
      btn_down_isdown = false;
    }
    if (btn_up_isdown)
    {
      if (sub_pos == 1) {
        sub_pos = 2;
      } else {
        sub_pos--;
      }
      update_display = true;
      btn_up_isdown = false;
    }

    if (btn_cancel_isdown) {
      c_page = wireless; return;;
    }
    if (btn_accept_isdown)
    {
      switch (sub_pos)
      {
        case 1: Serial.println(F("                                  *turned on bluetooth"));
        case 2: Serial.println(F("                                  *turned off bluetooth"));
      }
    }
    while (millis() - loopstart < 25) {
      delay(2);
    }
  }
}
//sim section
void sim_page(void)
{
  btn_cancel_isdown = false;
  btn_up_isdown = false;
  btn_down_isdown = false;
  btn_accept_isdown = false;
  bool update_display = true;
  uint32_t loopstart;
  uint8_t sub_pos = 1;
  while (true)
  {
    loopstart = millis();
    if (update_display)
    {
      update_display = false;
      clear_screen();
      Serial.println(F("welcome to sim section "));
      print_divider();
      print_selected(1, sub_pos); Serial.println(F("call"));
      print_selected(2, sub_pos); Serial.println(F("message"));
      Serial.println();
      Serial.println();
      print_divider();
              if(menu_selected(1, sub_pos))
      {
audioConnecttoSD("menu/eng/call.mp3");
      }
     else if(menu_selected(2, sub_pos))//C/en/alp/A.mp3
      {
audioConnecttoSD("menu/eng/message.mp3");
      }
    }
    keypress_detect();
    if (btn_down_isdown)
    {
      if (sub_pos == 2) {
        sub_pos = 1;
      } else {
        sub_pos++;
      }
      update_display = true;
      btn_down_isdown = false;
    }
    if (btn_up_isdown)
    {
      if (sub_pos == 1) {
        sub_pos = 2;
      } else {
        sub_pos--;
      }
      update_display = true;
      btn_up_isdown = false;
    }

    if (btn_cancel_isdown) {
      c_page = root_menu; return;;
    }
    if (btn_accept_isdown)
    {
      switch (sub_pos)
      {
        case 1: c_page = call; return;
        case 2: c_page = message; return;
      }
    }
    while (millis() - loopstart < 25) {
      delay(2);
    }
  }
}
void call_page()
{
  btn_cancel_isdown = false;
  btn_accept_isdown = false;
  bool update_display = true;
  uint32_t loopstart;
  while (true)
  {
    loopstart = millis();
    if (update_display)
    {
      update_display = false;
      clear_screen();
      Serial.println(F("        call"));
      print_divider();
      print_selected(1, 1); Serial.println(F("call to x"));
      Serial.println();
      print_divider();
    }
    keypress_detect();
    if (btn_cancel_isdown) {
      c_page = sim; return;
    }
    while (millis() - loopstart < 25) {
      delay(2);
    }
  }
}
void message_page()
{
  btn_cancel_isdown = false;
  btn_accept_isdown = false;
  bool update_display = true;
  uint32_t loopstart;
  while (true)
  {
    loopstart = millis();
    if (update_display)
    {
      update_display = false;
      clear_screen();
      Serial.println(F("        message"));
      print_divider();
      print_selected(1, 1); Serial.println(F("message to x"));
      Serial.println();
      print_divider();
    }
    keypress_detect();
    if (btn_cancel_isdown) {
      c_page = sim; return;
    }
    while (millis() - loopstart < 25) {
      delay(2);
    }
  }
}
//settings
void settings_page(void)
{
  btn_cancel_isdown = false;
  btn_up_isdown = false;
  btn_down_isdown = false;
  btn_accept_isdown = false;
  bool update_display = true;
  uint32_t loopstart;
  uint8_t sub_pos = 1;
  while (true)
  {
    loopstart = millis();
    if (update_display)
    {
      update_display = false;
      clear_screen();
      Serial.println(F("welcome to settings "));
      print_divider();
      print_selected(1, sub_pos); Serial.println(F("language"));
      print_selected(2, sub_pos); Serial.println(F("voice output"));
      print_selected(3, sub_pos); Serial.println(F("braille output"));
      print_selected(4, sub_pos); Serial.println(F("touch pen"));
      print_selected(5, sub_pos); Serial.println(F("power"));
      Serial.println();
      Serial.println();
      print_divider();
              if(menu_selected(1, sub_pos))
      {
audioConnecttoSD("menu/eng/language.mp3");
      }
     else if(menu_selected(2, sub_pos))//C/en/alp/A.mp3
      {
audioConnecttoSD("menu/eng/voice_output.mp3");
      }
      else if(menu_selected(3, sub_pos))//C/en/alp/A.mp3
      {
audioConnecttoSD("menu/eng/braille_output.mp3");
      }
      else if(menu_selected(4, sub_pos))//C/en/alp/A.mp3
      {
audioConnecttoSD("menu/eng/touch_pen.mp3");
      }
      else if(menu_selected(5, sub_pos))//C/en/alp/A.mp3
      {
audioConnecttoSD("menu/eng/power.mp3");
      }    
    }
    keypress_detect();
    if (btn_down_isdown)
    {
      if (sub_pos == settings_cnt) {
        sub_pos = 1;
      } else {
        sub_pos++;
      }
      update_display = true;
      btn_down_isdown = false;
    }
    if (btn_up_isdown)
    {
      if (sub_pos == 1) {
        sub_pos = settings_cnt;
      } else {
        sub_pos--;
      }
      update_display = true;
      btn_up_isdown = false;
    }

    if (btn_cancel_isdown) {
      c_page = root_menu; return;;
    }

    if (btn_accept_isdown)
    {
      switch (sub_pos)
      {
        case 1: c_page = language; return;
        case 2: c_page = voice_output; return;
        case 3: c_page = braille_output; return;
        case 4: c_page = touch_pen; return;
        case 5: c_page = power; return;
      }
    }

    while (millis() - loopstart < 25) {
      delay(2);
    }
  }
}
//language
void language_page()
{
  btn_cancel_isdown = false;
  btn_up_isdown = false;
  btn_down_isdown = false;
  btn_accept_isdown = false;
  bool update_display = true;
  uint32_t loopstart;
  uint8_t sub_pos = 1;
  while (true)
  {
    loopstart = millis();
    if (update_display)
    {
      update_display = false;
      clear_screen();
      Serial.println(F("welcome to language section "));
      print_divider();
      print_selected(1, sub_pos); Serial.println(F("english language"));
      print_selected(2, sub_pos); Serial.println(F("bangla language"));
      Serial.println();
      Serial.println();
      print_divider();
               if(menu_selected(1, sub_pos))
      {
audioConnecttoSD("menu/eng/english_language.mp3");
      }
     else if(menu_selected(2, sub_pos))//C/en/alp/A.mp3
      {
audioConnecttoSD("menu/eng/bengali_language.mp3");
      }
    }
    keypress_detect();
    if (btn_down_isdown)
    {
      if (sub_pos == 2) {
        sub_pos = 1;
      } else {
        sub_pos++;
      }
      update_display = true;
      btn_down_isdown = false;
    }
    if (btn_up_isdown)
    {
      if (sub_pos == 1) {
        sub_pos = 2;
      } else {
        sub_pos--;
      }
      update_display = true;
      btn_up_isdown = false;
    }

    if (btn_cancel_isdown) {
      c_page = settings; return;
    }
    if (btn_accept_isdown)
    {
      switch (sub_pos)
      {
        case 1: set_data = "E000000"; return;
        case 2: set_data = "B000000"; return;
      }
    }
    while (millis() - loopstart < 25) {
      delay(2);
    }
  }
}
//voice output
void voice_output_page()
{
  btn_cancel_isdown = false;
  btn_up_isdown = false;
  btn_down_isdown = false;
  btn_accept_isdown = false;
  bool update_display = true;
  uint32_t loopstart;
  uint8_t sub_pos = 1;
  while (true)
  {
    loopstart = millis();
    if (update_display)
    {
      update_display = false;
      clear_screen();
      Serial.println(F("welcome to voice output section "));
      print_divider();
      print_selected(1, sub_pos); Serial.println(F(" voice output enable"));
      print_selected(2, sub_pos); Serial.println(F("voice output disable"));
      Serial.println();
      Serial.println();
      print_divider();
               if(menu_selected(1, sub_pos))
      {
audioConnecttoSD("menu/eng/voice_enable.mp3");
      }
     else if(menu_selected(2, sub_pos))//C/en/alp/A.mp3
      {
audioConnecttoSD("menu/eng/voice_disable.mp3");
      }
    }
    keypress_detect();
    if (btn_down_isdown)
    {
      if (sub_pos == 2) {
        sub_pos = 1;
      } else {
        sub_pos++;
      }
      update_display = true;
      btn_down_isdown = false;
    }
    if (btn_up_isdown )
    {
      if (sub_pos == 1) {
        sub_pos = 2;
      } else {
        sub_pos--;
      }
      update_display = true;
      btn_up_isdown = false;
    }

    if (btn_cancel_isdown) {
      c_page = settings; return;
    }
    if (btn_accept_isdown)
    {
      switch (sub_pos)
      {
        case 1: Serial.println(F("                                  *voice output enabled"));
        case 2: Serial.println(F("                                  *voice output disabled"));
      }
    }
    while (millis() - loopstart < 25) {
      delay(2);
    }
  }
}
//braille output
void braille_output_page()
{
  btn_cancel_isdown = false;
  btn_up_isdown = false;
  btn_down_isdown = false;
  btn_accept_isdown = false;
  bool update_display = true;
  uint32_t loopstart;
  uint8_t sub_pos = 1;
  while (true)
  {
    loopstart = millis();
    if (update_display)
    {
      update_display = false;
      clear_screen();
      Serial.println(F("welcome to braille output section "));
      print_divider();
      print_selected(1, sub_pos); Serial.println(F(" braille display output enable"));
      print_selected(2, sub_pos); Serial.println(F("braille display output disable"));
      Serial.println();
      Serial.println();
      print_divider();
                 if(menu_selected(1, sub_pos))
      {
audioConnecttoSD("menu/eng/display_enable.mp3");
      }
     else if(menu_selected(2, sub_pos))//C/en/alp/A.mp3
      {
audioConnecttoSD("menu/eng/display_disable.mp3");
      }
    }
    keypress_detect();
    if (btn_down_isdown)
    {
      if (sub_pos == 2) {
        sub_pos = 1;
      } else {
        sub_pos++;
      }
      update_display = true;
      btn_down_isdown = false;
    }
    if (btn_up_isdown)
    {
      if (sub_pos == 1) {
        sub_pos = 2;
      } else {
        sub_pos--;
      }
      update_display = true;
      btn_up_isdown = false;
    }

    if (btn_cancel_isdown) {
      c_page = settings; return;
    }
    if (btn_accept_isdown)
    {
      switch (sub_pos)
      {
        case 1: Serial.println(F("                                  *braille output enabled"));
        case 2: Serial.println(F("                                  *braille output disabled"));
      }
    }
    while (millis() - loopstart < 25) {
      delay(2);
    }
  }
}
//touch pen section
void touch_pen_page()
{
  btn_cancel_isdown = false;
  btn_up_isdown = false;
  btn_down_isdown = false;
  btn_accept_isdown = false;
  bool update_display = true;
  uint32_t loopstart;
  uint8_t sub_pos = 1;
  while (true)
  {
    loopstart = millis();
    if (update_display)
    {
      update_display = false;
      clear_screen();
      Serial.println(F("welcome to touch pen section "));
      print_divider();
      print_selected(1, sub_pos); Serial.println(F(" touch pen enable"));
      print_selected(2, sub_pos); Serial.println(F("touch pen disable"));
      Serial.println();
      Serial.println();
      print_divider();
                 if(menu_selected(1, sub_pos))
      {
audioConnecttoSD("menu/eng/touch_pen_enable.mp3");
      }
     else if(menu_selected(2, sub_pos))//C/en/alp/A.mp3
      {
audioConnecttoSD("menu/eng/touch_pen_disable.mp3");
      }
    }
    keypress_detect();
    if (btn_down_isdown)
    {
      if (sub_pos == 2) {
        sub_pos = 1;
      } else {
        sub_pos++;
      }
      update_display = true;
      btn_down_isdown = false;
    }
    if (btn_up_isdown)
    {
      if (sub_pos == 1) {
        sub_pos = 2;
      } else {
        sub_pos--;
      }
      update_display = true;
      btn_up_isdown = false;
    }

    if (btn_cancel_isdown) {
      c_page = settings; return;
    }
    if (btn_accept_isdown)
    {
      switch (sub_pos)
      {
        case 1: Serial.println(F("                                  *pen input enabled"));
        case 2: Serial.println(F("                                  *pen input disabled"));
      }
    }
    while (millis() - loopstart < 25) {
      delay(2);
    }
  }
}
//power
void power_page()
{
  btn_cancel_isdown = false;
  btn_up_isdown = false;
  btn_down_isdown = false;
  btn_accept_isdown = false;
  bool update_display = true;
  uint32_t loopstart;
  uint8_t sub_pos = 1;
  while (true)
  {
    loopstart = millis();
    if (update_display)
    {
      update_display = false;
      clear_screen();
      Serial.println(F("welcome power section "));
      print_divider();
      print_selected(1, sub_pos); Serial.println(F(" power off"));
      print_selected(2, sub_pos); Serial.println(F("restart"));
      Serial.println();
      Serial.println();
      print_divider();
                  if(menu_selected(1, sub_pos))
      {
audioConnecttoSD("menu/eng/power_off.mp3");
      }
     else if(menu_selected(2, sub_pos))//C/en/alp/A.mp3
      {
audioConnecttoSD("menu/eng/restart.mp3");
      }
    }
    keypress_detect();
    if (btn_down_isdown)
    {
      if (sub_pos == 2) {
        sub_pos = 1;
      } else {
        sub_pos++;
      }
      update_display = true;
      btn_down_isdown = false;
    }
    if (btn_up_isdown )
    {
      if (sub_pos == 1) {
        sub_pos = 2;
      } else {
        sub_pos--;
      }
      update_display = true;
      btn_up_isdown = false;
    }

    if (btn_cancel_isdown) {
      c_page = settings; return;
    }
    if (btn_accept_isdown)
    {
      switch (sub_pos)
      {
        case 1: Serial.println(F("                                  *power off"));
        case 2: ESP.restart();
      }
    }
    while (millis() - loopstart < 25) {
      delay(2);
    }
  }
}

void print_selected( uint8_t x,  uint8_t y)
{
  if (x == y)Serial.print(F("->  "));
  else Serial.print(F("    "));
}
bool menu_selected(uint8_t x,  uint8_t y)
{
if (x == y)return true;
else return false;
}
void  clear_screen()
{
  for (uint8_t i = 0; i < 100; i++)Serial.println();
}
void  print_divider()
{
  for (uint8_t i = 0; i < 20; i++)Serial.print("--");
  Serial.println();
}
String braille_input()
{
  String data = set_data;
  for (;;) {
    if (customKeypad.getKeys())
    {
      for (int i = 0; i < LIST_MAX; i++) // Scan the whole key list.
      {
        if ( customKeypad.key[i].stateChanged )   // Only find keys that have changed state.
        {
          switch (customKeypad.key[i].kstate) {  // Report active key state : IDLE, PRESSED, HOLD, or RELEASED
            case PRESSED:
              char ch = customKeypad.key[i].kchar;
              if (ch > 48 && ch < 55)
                data[((String)ch).toInt()] = '1';
              else if (customKeypad.key[i].kchar == 'e') {
                return data;
              }
              break;
          }
        }
      }
    }
  }
}
char kerneldata_to_userdata(String data)
{
  for (int i = 0; i < sizeof(eng) / sizeof(eng[0]); i++)
  {
    if (data.compareTo(eng[i].kerneldata) == 0)
    {
      //if(eng[i].userdata!="B000000")
      return eng[i].userdata;
    }
  }
}
String userdata_to_kerneldata(String data)
{
  for (int i = 0; i < 10; i++)
  {
    /* if (data.compareTo(arr[i].userdata) == 0)
      {
       if (arr[i].kerneldata != "B000000")
         return arr[i].kerneldata;
      }*/
  }
}

void readFile(fs::FS &fs, const char * path) {
  Serial.printf("Reading file: %s\n", path);

  File file = fs.open(path);
  if (!file) {
    Serial.println("Failed to open file for reading");
    return;
  }

  Serial.print("Read from file: ");
  s="";//audiostatus()
  int cnt=0;
  while (file.available()) {
    char charRead = file.read();
      s += (String)charRead;
      if(charRead==' ')cnt++;
    if(charRead=='.'||cnt==25||!file.available())
 { audioConnecttoSpeech(s.c_str(),"en");
 s="";
 cnt=0;
 while(audiostatus()){Serial.println("audio playing");}
 }
  }
  Serial.println(s);
  file.close();
}

void writeFile(fs::FS &fs, const char * path, String message) {
  Serial.printf("Writing file: %s\n", path);

  File file = fs.open(path, FILE_WRITE);
  if (!file) {
    Serial.println("Failed to open file for writing");
    return;
  }
  if (file.print(message)) {
    Serial.println("File written");
  } else {
    Serial.println("Write failed");
  }

  file.close();
}

void appendFile(fs::FS &fs, const char * path, String message) {
  File file = fs.open(path, FILE_APPEND);
  if (!file) {
    Serial.println("Failed to open file for appending");
    return;
  }
  if (file.print(message)) {
    Serial.println("Message appended");
  } else {
    Serial.println("Append failed");
  }
  file.close();
}

void keypress_detect()
{
  int cnt = 0;
  char customKey = customKeypad.getKey();
  if (customKey == 'e') {
    btn_accept_isdown = true;
  }
  if (customKey == 'u') {
    btn_up_isdown = true;
  }
  if (customKey == 'd') {
    btn_down_isdown = true;
  }
  if (customKey == 'c') {
    btn_cancel_isdown = true;
  }
  if (customKey == 'b'&&c_page==doc_writing) {
    Serial.println("backspace");
    btn_backspace_isdown = true;
  }
  if (customKey == 'C') {
    capslock = !capslock;
    if (capslock) {
      Serial.println("capslock on");
    }
    if (!capslock) {
      Serial.println("capslock off");
    }
  }
  if (customKey == 'n') {
    numlock = !numlock;
    if (numlock) {
      Serial.println("numlock on");
    }
    if (!numlock) {
      Serial.println("numlock off");
    }
  }
}
//****************************************************************************************
//                                          GSM                                 
//****************************************************************************************
void send_sms(String phn_num,String msg){
 
  Serial2.println("AT+CMGF=1");
  waitForResponse();

  Serial2.println("AT+CNMI=1,2,0,0,0");
 
  waitForResponse();
  String msg_mode="AT+CMGS=\""+phn_num+"\"\r";
  Serial2.print(msg_mode);
  waitForResponse();
   Serial2.print(msg);
   Serial2.write(0x1A);
  waitForResponse();
}

void make_call(String phn_num){
  phn_num="ATD"+phn_num+";";
  Serial2.println(phn_num);
  delay(40000);
   waitForResponse();
}

void waitForResponse(){
  delay(1000);
  while(Serial2.available()){
 buff = Serial2.readString();
    Serial.print(buff);
  }
  //Serial2.read();
}

void find_my_keyboard(String phn_num,String msg,int alert_mode)
{
  int c=3;
if(alert_mode==1)send_sms(phn_num,msg);
if(alert_mode==2)
{
  while(c--) { waitForResponse();if(buff.indexOf("NO CARRIER")>0)break;else make_call(phn_num);}
}
if(alert_mode==3)
{
  send_sms(phn_num,msg);
  delay(40000);
 while(c--) { waitForResponse();if(buff.indexOf("NO CARRIER")>0)break;else make_call(phn_num);}

}  
 
}
//****************************************************************************************
//                        numlock & backspace                                            *
//****************************************************************************************
bool numlock_f(char udata)
{
      if (isDigit(udata))
     return true;
     else 
     {
audioConnecttoSD("C/sounds/beep.mp3");
return false;
     }
}
void backspace_f(fs::FS &fs,const char * path)
{
  File file = fs.open(path, FILE_WRITE);
  String all_text;

 while (file.available()) {
    char charRead = file.read();
      all_text += (String)charRead;
 }
  file.close();
    int length = all_text.length();
    all_text[length - 1] = '\0';
     Serial.println(all_text);
     writeFile(SD, "/text.txt",all_text);
    btn_backspace_isdown = false;
  Serial.println(all_text);
   
}
//****************************************************************************************
//                                   A U D I O _ T A S K                                 *
//****************************************************************************************

void audioTask(void *parameter) {
    CreateQueues();
    if(!audioSetQueue || !audioGetQueue){
        log_e("queues are not initialized");
        while(true){;}  // endless loop
    }

    struct audioMessage audioRxTaskMessage;
    struct audioMessage audioTxTaskMessage;

    audio.setPinout(I2S_BCLK, I2S_LRC, I2S_DOUT);
    audio.setVolume(20); // 0...21

    while(true){
        if(xQueueReceive(audioSetQueue, &audioRxTaskMessage, 1) == pdPASS) {
            if(audioRxTaskMessage.cmd == SET_VOLUME){
                audioTxTaskMessage.cmd = SET_VOLUME;
                audio.setVolume(audioRxTaskMessage.value);
                audioTxTaskMessage.ret = 1;
                xQueueSend(audioGetQueue, &audioTxTaskMessage, portMAX_DELAY);
            }
            else if(audioRxTaskMessage.cmd == CONNECTTOHOST){
                audioTxTaskMessage.cmd = CONNECTTOHOST;
                audioTxTaskMessage.ret = audio.connecttohost(audioRxTaskMessage.txt);
                xQueueSend(audioGetQueue, &audioTxTaskMessage, portMAX_DELAY);
            }
            else if(audioRxTaskMessage.cmd == CONNECTTOSD){
                audioTxTaskMessage.cmd = CONNECTTOSD;
                audioTxTaskMessage.ret = audio.connecttoSD(audioRxTaskMessage.txt);
                xQueueSend(audioGetQueue, &audioTxTaskMessage, portMAX_DELAY);
            }
            else if(audioRxTaskMessage.cmd == GET_VOLUME){
                audioTxTaskMessage.cmd = GET_VOLUME;
                audioTxTaskMessage.ret = audio.getVolume();
                xQueueSend(audioGetQueue, &audioTxTaskMessage, portMAX_DELAY);
            }
             else if(audioRxTaskMessage.cmd == GET_AUDIOSTATUS){
                audioTxTaskMessage.cmd = GET_AUDIOSTATUS;
                audioTxTaskMessage.ret = audio.isRunning();
                xQueueSend(audioGetQueue, &audioTxTaskMessage, portMAX_DELAY);
            }
            else if(audioRxTaskMessage.cmd == CONNECTTOSPEECH){
                audioTxTaskMessage.cmd = CONNECTTOSPEECH;
                audioTxTaskMessage.ret =audio.connecttospeech(audioRxTaskMessage.txt,audioRxTaskMessage.lang);
                xQueueSend(audioGetQueue, &audioTxTaskMessage, portMAX_DELAY);
            }
            else{
                log_i("error");
            }
        }
        audio.loop();
        if (!audio.isRunning()) {
          sleep(1);
        }
    }
}

void audioInit() {
    xTaskCreatePinnedToCore(
        audioTask,             /* Function to implement the task */
        "audioplay",           /* Name of the task */
        5000,                  /* Stack size in words */
        NULL,                  /* Task input parameter */
        2 | portPRIVILEGE_BIT, /* Priority of the task */
        NULL,                  /* Task handle. */
        1                      /* Core where the task should run */
    );
}
audioMessage transmitReceive(audioMessage msg){
    xQueueSend(audioSetQueue, &msg, portMAX_DELAY);
    if(xQueueReceive(audioGetQueue, &audioRxMessage, portMAX_DELAY) == pdPASS){
        if(msg.cmd != audioRxMessage.cmd){
            log_e("wrong reply from message queue");
        }
    }
    return audioRxMessage;
}

void audioSetVolume(uint8_t vol){
    audioTxMessage.cmd = SET_VOLUME;
    audioTxMessage.value = vol;
    audioMessage RX = transmitReceive(audioTxMessage);
}

uint8_t audioGetVolume(){
    audioTxMessage.cmd = GET_VOLUME;
    audioMessage RX = transmitReceive(audioTxMessage);
    return RX.ret;
}

bool audioConnecttohost(const char* host){
    audioTxMessage.cmd = CONNECTTOHOST;
    audioTxMessage.txt = host;
    audioMessage RX = transmitReceive(audioTxMessage);
    return RX.ret;
}

bool audioConnecttoSD(const char* filename){
    audioTxMessage.cmd = CONNECTTOSD;
    audioTxMessage.txt = filename;
    audioMessage RX = transmitReceive(audioTxMessage);
    return RX.ret;
}
void audio_info(const char *info){
    Serial.print("info        "); Serial.println(info);
}
bool audioConnecttoSpeech(const char* speech,const char* language){
   audioTxMessage.cmd= CONNECTTOSPEECH;
   audioTxMessage.txt= speech;
   audioTxMessage.lang= language;
   audioMessage RX = transmitReceive(audioTxMessage);
   return RX.ret;
}

bool audiostatus(){
   audioTxMessage.cmd = GET_AUDIOSTATUS;
    audioMessage RX = transmitReceive(audioTxMessage);
    return RX.ret;
}
 
//****************************************************************************************
//                                  end audio portion                                          *
//****************************************************************************************

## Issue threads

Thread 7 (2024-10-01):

We Need A Serious Correction in PCB!!!!

TheZeroHz, 2024-10-01:
**Several Issues found!!!!!!**
- Don't use pin 14 for vibrator directly! It consume much current which will fry our MCU!
- Don't use strapping pin 45 as keypad matrix. Replace 45 with pin 1.
- Don't use strapping pin 46 as TFT_MISO. Replace 46 with pin 2.
- Take Proper steps for reverse polarity protection,Power Supply noise!!!!

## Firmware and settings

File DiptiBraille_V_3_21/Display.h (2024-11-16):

#ifndef DISPLAY_H
#define DISPLAY_H

#include <Arduino.h>  // Include this if you are using Arduino platform

#define DISPLAY_ENABLE true
#define DISPLAY_DISABLE false
#define DEFAULT_STATE DISPLAY_DISABLE
#define DEFAULT_FREQUENCY 25 //Working Well
#define DEFAULT_COOLINGFACTOR 5
#define DEFAULT_BURNINGFACTOR 2
#define RESET_CODE 128
#define IDLE_CODE 0
#define USE_SHIFT_REGISTER 1

struct DisplaySettings {
    int STCP, DS, SHCP, frequency, quantity;
    bool state;
    float cooling_coefficient, burning_coefficient;
};

class Display {
protected:
    float version = 1.01;
    DisplaySettings Settings;
    void pushToRegister(int base_10);
    int binstrToint(String binary_string);

public:
    String printData="";
    void loop();
    void setPins(int dataPin, int clockPin, int latchPin, int numOFcells);
    void initDisplay(int refresh_rate);
    void disable();
    void enable();
    void setFrequency(int hz);
    void setFactor(float cool, float burn);
    bool isEnabled();
    float getVersion();
    int getFrequency();
    void clear();
    void writeDec(int DATA_DECIMAL);
    void writeBinStr(String DATA_BINARY_STRING);
    void writeChar(char DATA_CHAR);
};

#endif // DISPLAY_H

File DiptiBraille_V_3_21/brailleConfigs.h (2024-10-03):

#ifndef BRAILLECONFIGS_H
#define BRAILLECONFIGS_H
#include<Arduino.h>
bool KeyBoard_Connected=false;
BleKeyboard bleKeyboard;

#define HAS_VIBRATOR
#define HAS_EXTERNAL_DISPLAY
#define HAS_MONITOR

#define DEBUG_AUDIO false
#define DEBUG_WEBSHARE true
#define braille_version "3.21"
#define version_type " beta"
String update_url="https://drive.google.com/uc?id=1F_yV9xp4O4s3-oyEsIUqHSSqvUNJXbRn&export=download";
String latest_update_loc="/C/firmware/current/update.bin";
String failsafe_update_loc="/C/firmware/failsafe/update.bin";
String previous_update_loc="/C/firmware/previous/update.bin";

#define boot_sound "C/sounds/bootup.mp3"
#define shutdown_sound "C/sounds/shutdown.mp3"

#define BUTTON_PIN_BITMASK 0x100 // 2^8 in hex  Pin 8 OK PCB
// SD CARD
#define SD_CS 10  //OK PCB
#define SPI_MOSI 11 //OK PCB
#define SPI_MISO 13 //OK PCB
#define SPI_SCK 12  //OK PCB
// I2S Amplifier
#define I2S_DOUT 6 //Some times labeled as DIN OK PCB
#define I2S_BCLK 5 // OK PCB
#define I2S_LRC 4 // OK PCB

void print_wakeup_reason(){
  esp_sleep_wakeup_cause_t wakeup_reason;

  wakeup_reason = esp_sleep_get_wakeup_cause();

  switch(wakeup_reason)
  {
    case ESP_SLEEP_WAKEUP_EXT0 : Serial.println("Wakeup caused by external signal using RTC_IO"); break;
    case ESP_SLEEP_WAKEUP_EXT1 : Serial.println("Wakeup caused by external signal using RTC_CNTL"); break;
    case ESP_SLEEP_WAKEUP_TIMER : Serial.println("Wakeup caused by timer"); break;
    case ESP_SLEEP_WAKEUP_TOUCHPAD : Serial.println("Wakeup caused by touchpad"); break;
    case ESP_SLEEP_WAKEUP_ULP : Serial.println("Wakeup caused by ULP program"); break;
    default : Serial.printf("Wakeup was not caused by deep sleep: %d\n",wakeup_reason); break;
  }
}

#endif

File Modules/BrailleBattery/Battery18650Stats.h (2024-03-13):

/* 
 *  18650 Ion-Li battery
 */

#ifndef Battery18650Stats_H_
#define Battery18650Stats_H_

#include "Arduino.h"

#define DEFAULT_PIN 35
#define DEFAULT_CONVERSION_FACTOR 1.705
#define DEFAULT_READS 1024

class Battery18650Stats {
 public:
  Battery18650Stats();
  ~Battery18650Stats();
  Battery18650Stats(int adcPin);
  Battery18650Stats(int adcPin, double conversionFactor);
  Battery18650Stats(int adcPin, double conversionFactor, int reads);

  int getBatteryChargeLevel(bool useConversionTable = false);
  double getBatteryVolts();

 private:
  int _adcPin;
  int _reads;
  double _conversionFactor;
  double *_conversionTable = nullptr;

  void _initConversionTable();
  int _getChargeLevelFromConversionTable(double volts);
  int _calculateChargeLevel(double volts);
  int _avgAnalogRead(int pinNumber, int reads);
  double _analogReadToVolts(int readValue);
};

#endif

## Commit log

2023-12-25 Add files via upload
    Added WebShare. Webshare is a application where the users can give their storage access to the local network.
    Webshare is called in bluetooth segment just for test purpose. Later on it should have a dedicated portion in wireless section.
    [Note: WebShare Is Implemented With RTOS]
2023-12-26 Add files via upload
    Fixed Display Shift Register Bug
    [DiptiBraille_V_3.15.ino, Display.cpp, Display.h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]
2024-10-03 Fixed PCB pins
